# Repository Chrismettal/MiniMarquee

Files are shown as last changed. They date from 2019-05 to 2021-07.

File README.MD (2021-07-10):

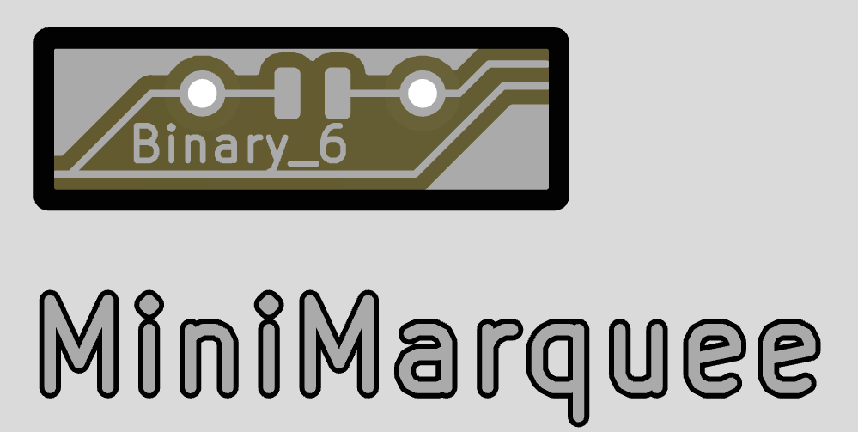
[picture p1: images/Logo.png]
MiniMarqueev0.2Logo


# MOVING TO GITLAB

This project has been moved to Gitlab and will NOT be updated here anymore!

https://gitlab.com/Chrismettal/MiniMarquee

# Update

v0.3 newly uses only a 10uF input cap instead of a 100uF one, since the inrush current when plugging in your PSU made some cheaper 100uF caps fail in rare occasions even with 50% volate derating. a 10uF 35 V cap is effectively using a 2/3 derating and is much less likely to fail, even when cheaper caps are used. Because of the violence of failing tantalum caps a v0.4 will be made that does not use tantalums at all in the future. For that reason v0.3 gerbers are not tested, but have just been generated after changing the silkscreen value of the input cap.

# Buying

I have opened up a Tindie store, carrying PCBs and DIY kits as well as 3D printed parts for this and other projects!



## What is this

Small marquees for standalone decoration with backlit signs, including output for up to 25 W of RGB LED strip.

Might be used for multiple consoles to have the specific sign and indirect strip lighting light up with the console.



## Capabilities

At the moment 15 light scenes can be hardcoded including static light ones and fading between 2 colors. More complex fades can be accomplished at will with any number of calculations with the iFade variables. The amount of light scenes and their values can be modified in the source. The same light scenes will be used for the backlight and the RGB strip output, but the two "zones" can be individually set to display a different scene to enable a contrast between the sign and indirect lighting. A single button steps through the light scenes for the specific zones. The current light scene is always saved in EEPROM to stay persistent between power cycles.

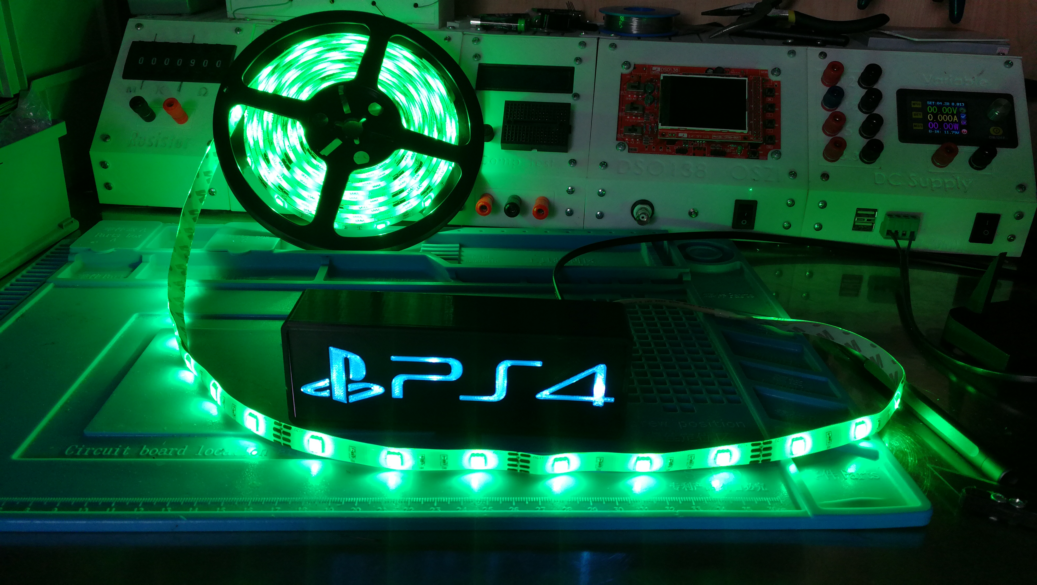
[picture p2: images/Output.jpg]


## DIY

**Be sure to jump straight to the [Wiki](https://github.com/Chrismettal/MiniMarquee/wiki) for detailed build instructions**

All the files are open source. The gerber files as well as the KiCAD project files can be found to get the PCBs made. Alternatively you can just write me. 

The case as well as all the signs need to be 3d printed. For the signs at least a 2-color extruder is required. I print all the parts in PETG because of the selection of transparent materials. The lowermost part i print in white for case internal reflections but if you only have a dual extruder setup you can print the lower and upper parts both in black and the actual logo in your color of choice.

Soldering requires some SMD capabilities. The QFP32 chip is the hardest but with a bit of flux is actually quite doable.

You don't need to change anything in the source if you are fine with the preconfigured lightscenes.
All light scenes are hardcoded in the **LightSceneEvaluation()** function. See the commented examples to make your own scenes. ALso check out the [light scene documentation](https://github.com/Chrismettal/MiniMarquee/wiki/Editing-lightscenes).
I used [PlatformIO](https://platformio.org/) on Visual Studio Code for programming. You could upload the code with the Arduino IDE but i recommend giving PlatformIO a try as you won't have to deal with the libraries etc. yourself.
An ICSP programmer is required to upload code to the board. I used a cheap UsbTiny device but you could use an *Arduino as ISP* for example.

A detailed building guide can be found [here](https://github.com/Chrismettal/MiniMarquee/wiki/Build-guide).

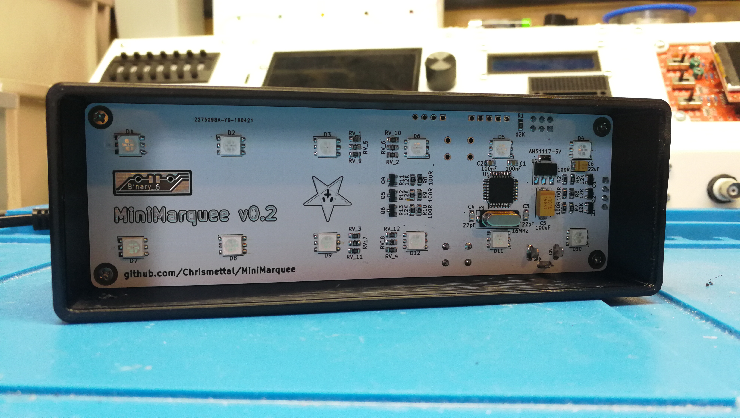
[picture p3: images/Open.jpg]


## Power

The device can be powered directly by a 12 V DC power supply. In my usecase the "master" device that controls the power to the individual consoles also switches on/off the power to the marquees, but you could power the marquees directly from the console using DC-DC converters to make the marquee always switch on with the console. 

## Versions

The current PCB version is v0.2.
The source code is made to be adaptable to both v0.2 and v0.1 PCBs to use with the old revision of the PCB. By default v0.2 is defined in the software. You will have to uncomment the "#define PCB_v0_1" to use the code with the old v0.1 PCB version, should you happen to get your hands on one.

## Controls

- Button short click    --> Next lightscene in current light zone
- Button double click   --> Previous lightscene in current light zone
- Button long click     --> Switch between which light zone to change

The device can just be switched on and off by cutting the power to it. It will remember its lightscenes for the next boot.

## Scenes

For now 15 lightscenes are precoded:

- Red
- Green
- Blue
- Sky Blue
- Warm white
- Cold white
- Yelow
- Orange
- Purple
- Olive
- Slow fade between Red and Green
- Slow fade between Green and Blue
- Slow fade between Blue and Red
- Slow fade between Yellow and Blue
- Breathing white

For not the Scenes are the same for internal and external lightzone but they don't have to be, should you want to change that.

## Signs

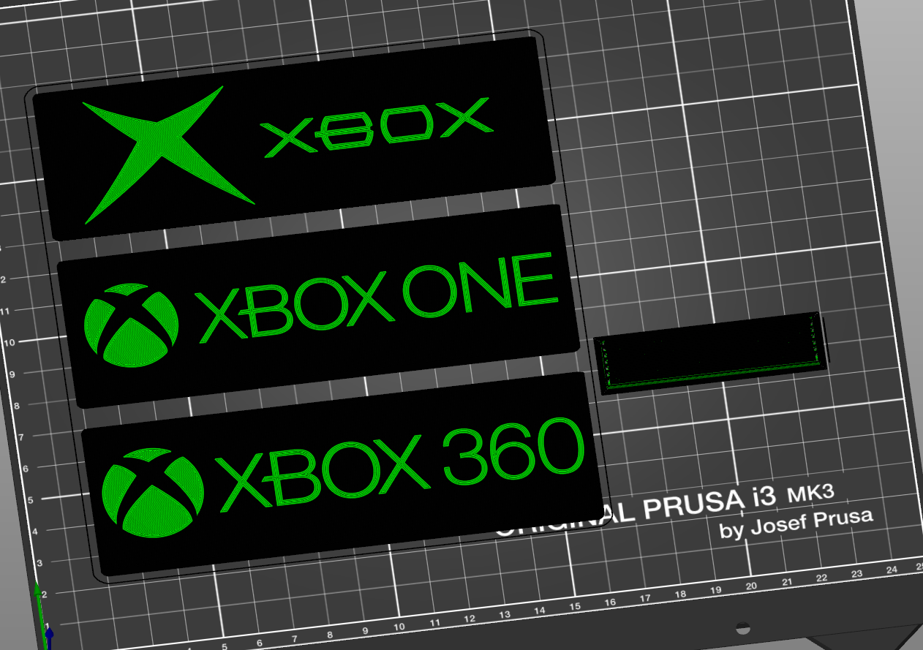
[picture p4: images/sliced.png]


This is an example of some of the designed signs. I am still in the process of printing out every one of them so i don't yet have pictures of all signs ready.

I also uploaded the "RawSign" files in the 3d printable folder so you can design your own signs. Be sure to reupload them either as a remix on [The Thingiverse page](https://www.thingiverse.com/thing:3683055) or somewhere else where i can feed them back into here.

Here is a list of the already made signs:

- [ ]  Nintendo
- [x]  NES
- [x]  SNES
- [x]  N64
- [x]  GC
- [x]  Wii
- [x]  WiiU
- [x]  Switch
- [x]  PS1
- [x]  PS2
- [x]  PS3
- [x]  PS4
- [x]  Xbox Classic
- [x]  Xbox 360
- [x]  Xbox One
- [ ]  Sega
- [x]  Master System
- [x]  Genesis
- [ ]  Megadrive
- [x]  Dreamcast
- [x]  Atari 2600
- [x]  NeoGeo
- [x]  Commodore
- [ ]  PC Engine
- [ ]  Turbografx 16
- [x]  Diffuse plate for stickers

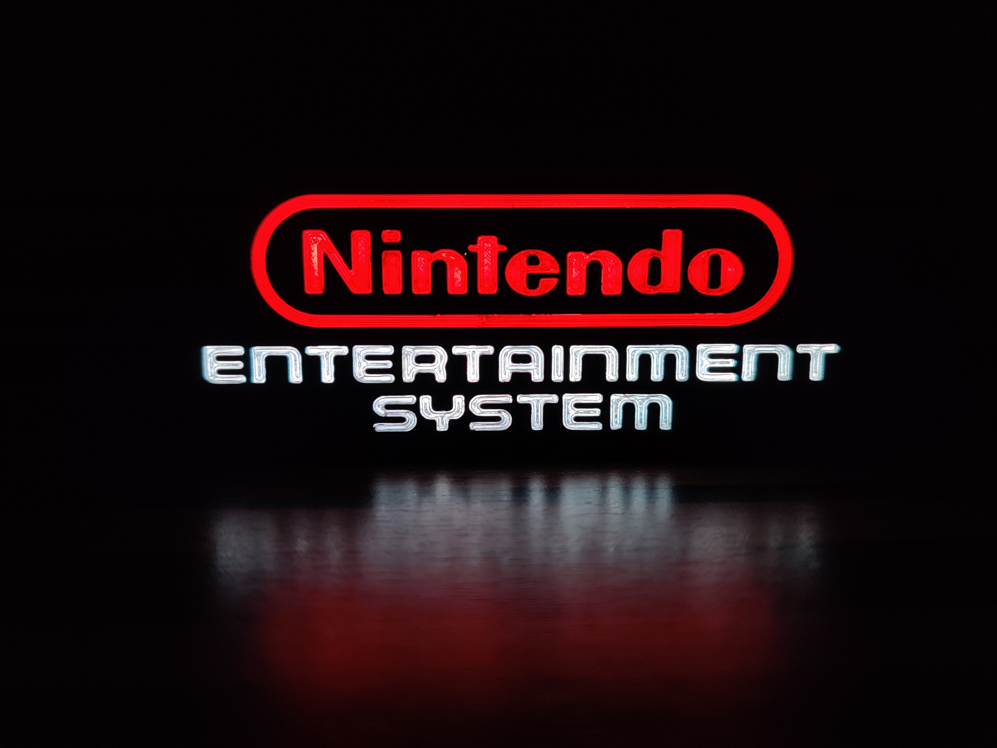
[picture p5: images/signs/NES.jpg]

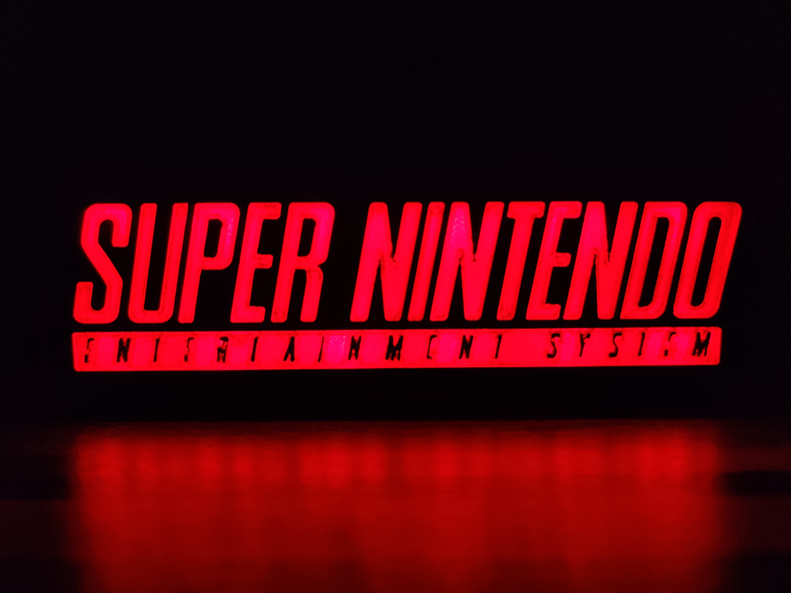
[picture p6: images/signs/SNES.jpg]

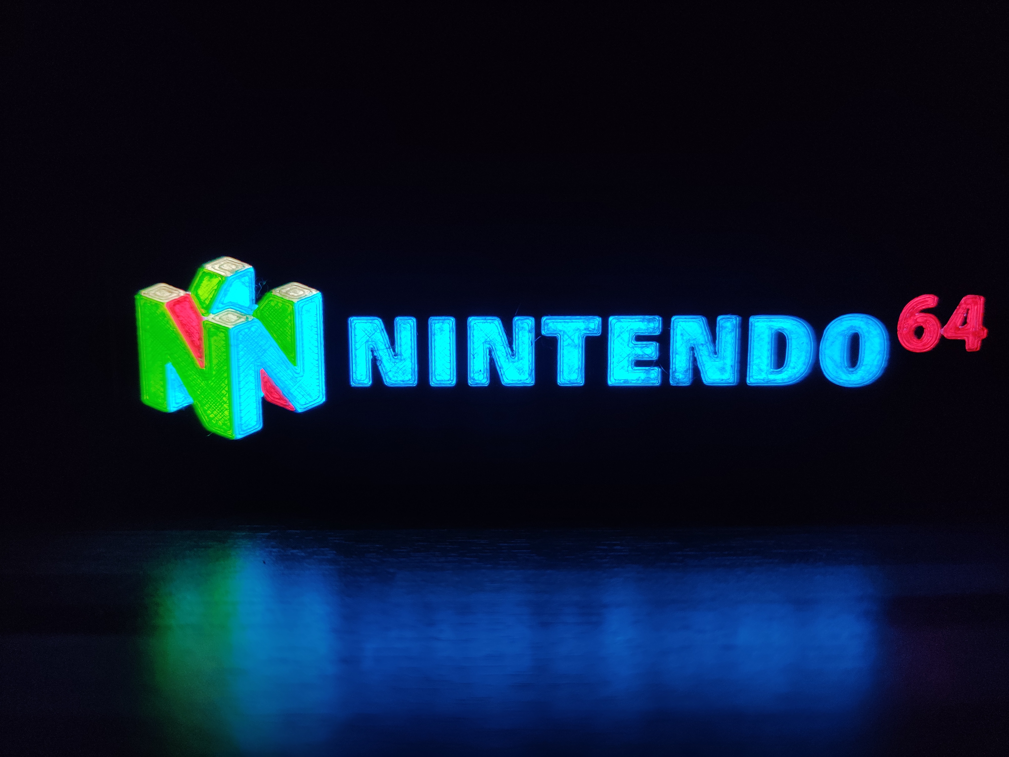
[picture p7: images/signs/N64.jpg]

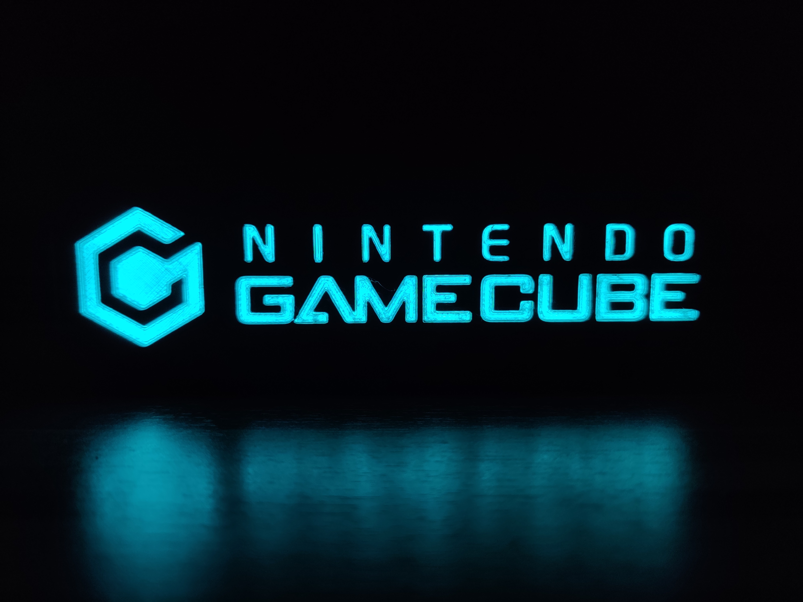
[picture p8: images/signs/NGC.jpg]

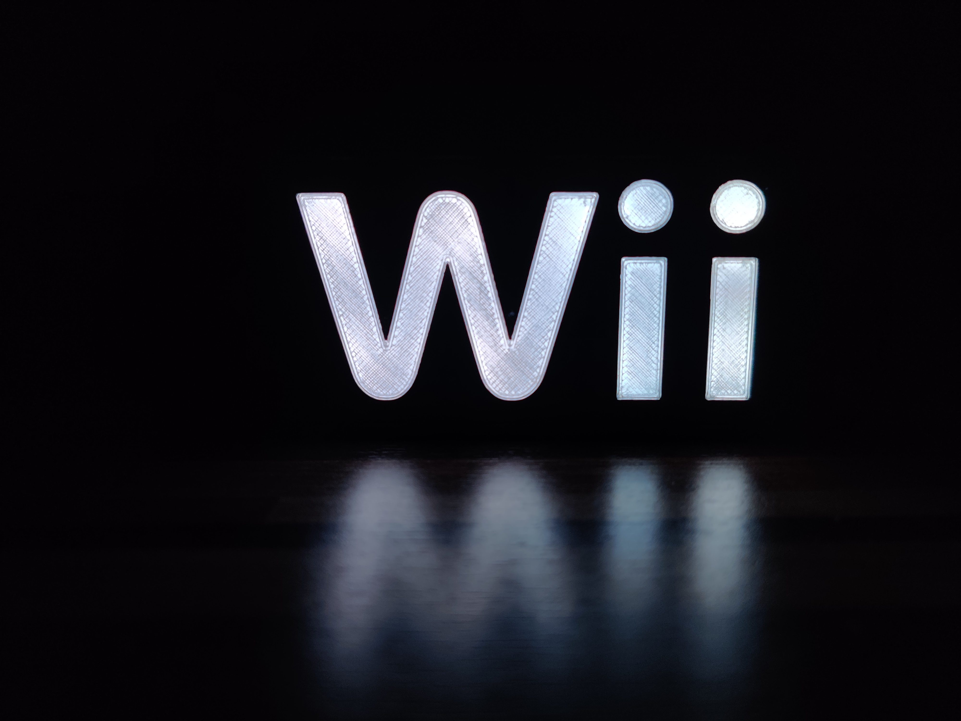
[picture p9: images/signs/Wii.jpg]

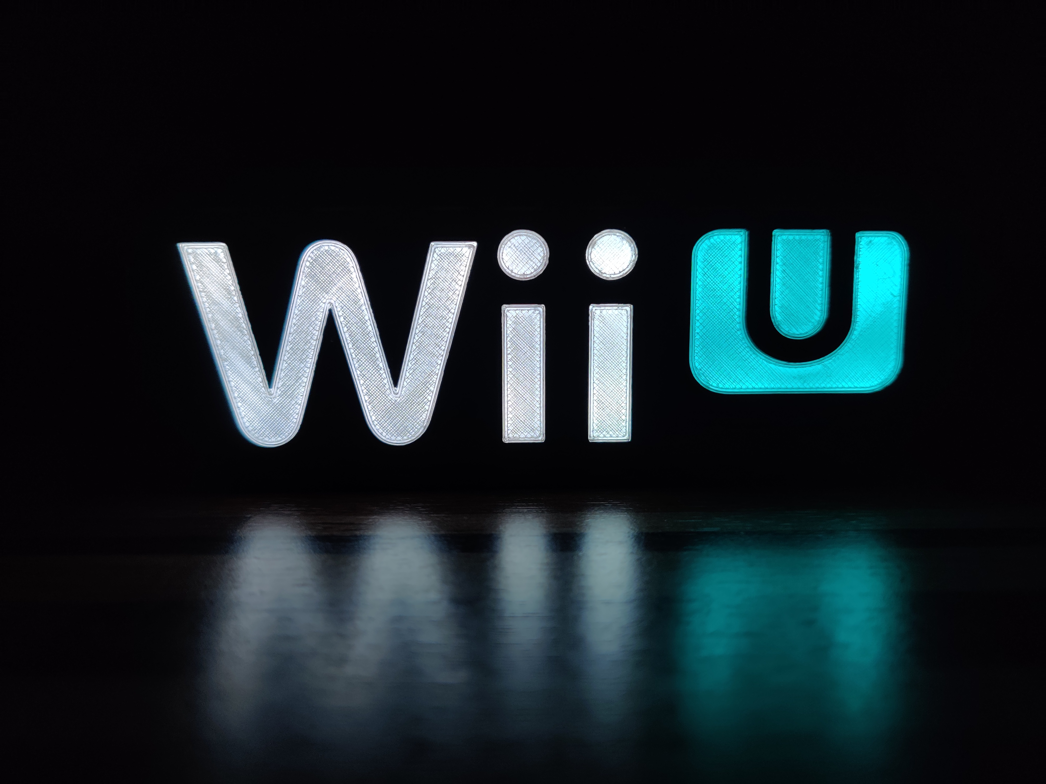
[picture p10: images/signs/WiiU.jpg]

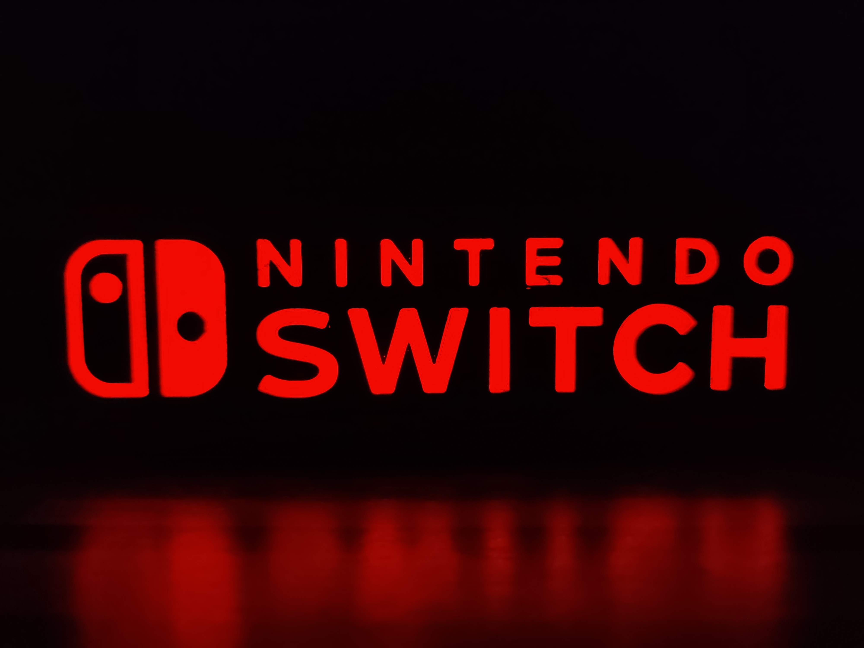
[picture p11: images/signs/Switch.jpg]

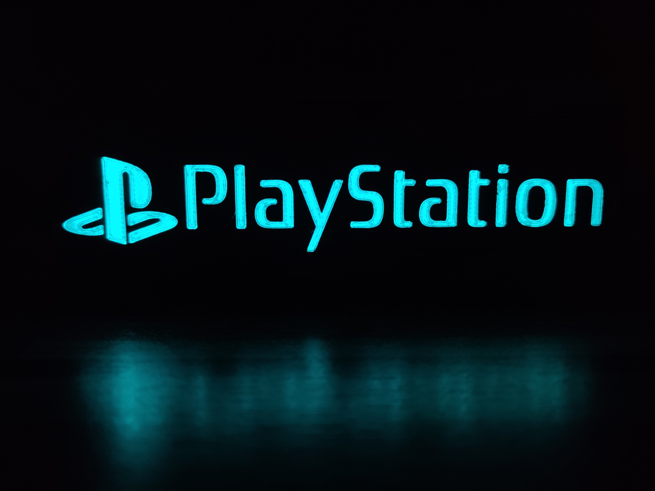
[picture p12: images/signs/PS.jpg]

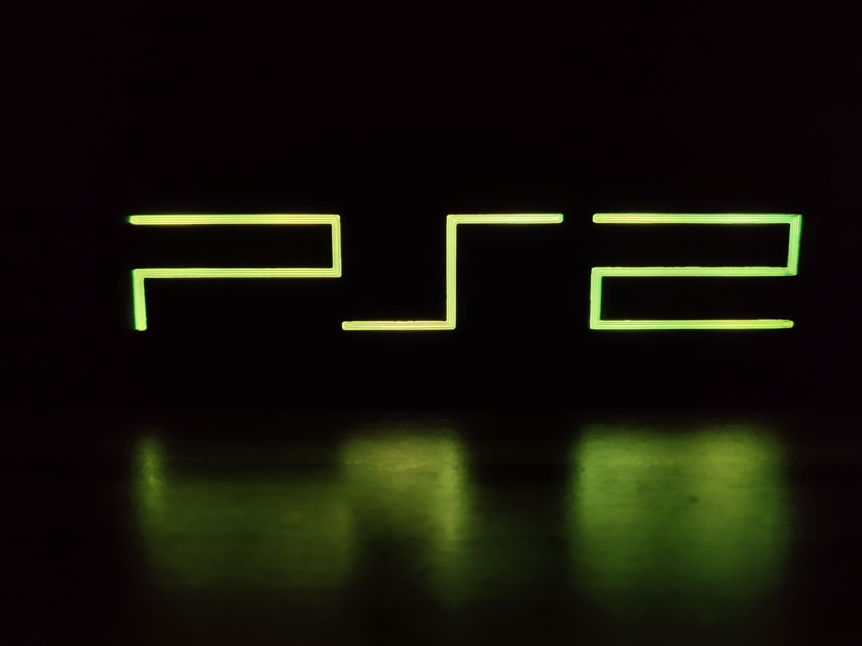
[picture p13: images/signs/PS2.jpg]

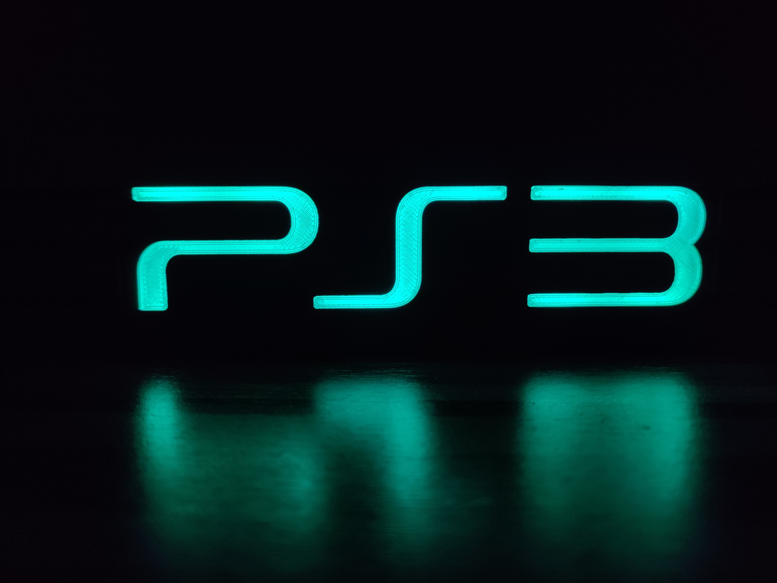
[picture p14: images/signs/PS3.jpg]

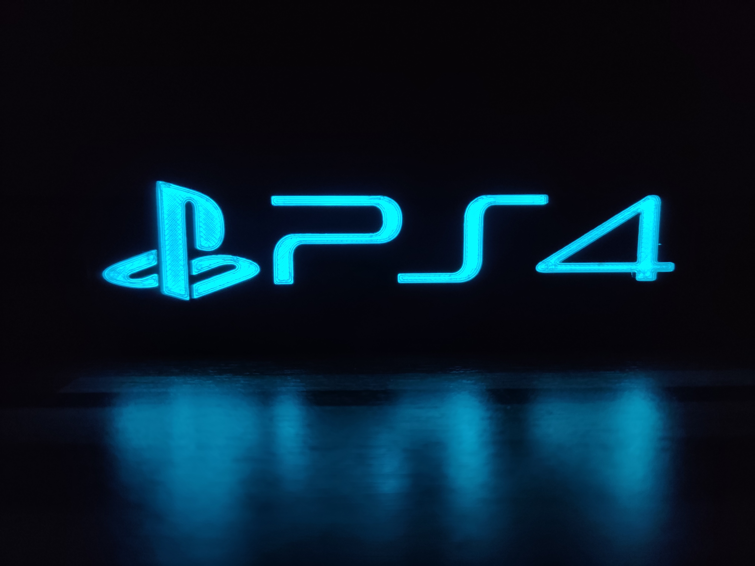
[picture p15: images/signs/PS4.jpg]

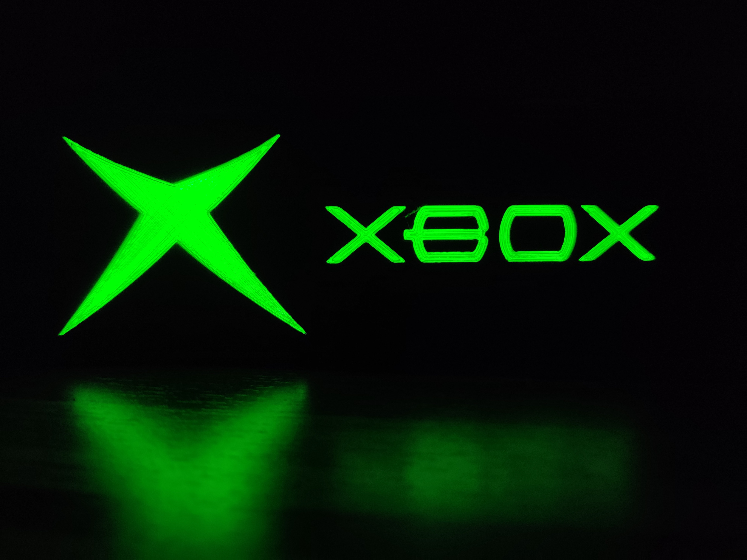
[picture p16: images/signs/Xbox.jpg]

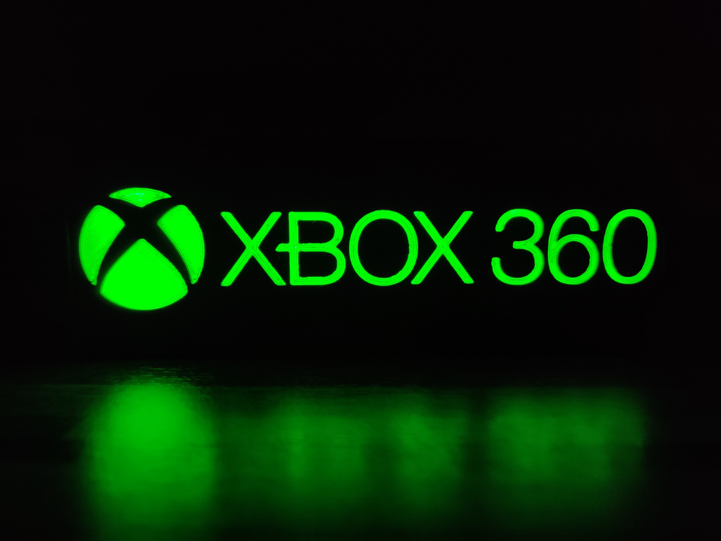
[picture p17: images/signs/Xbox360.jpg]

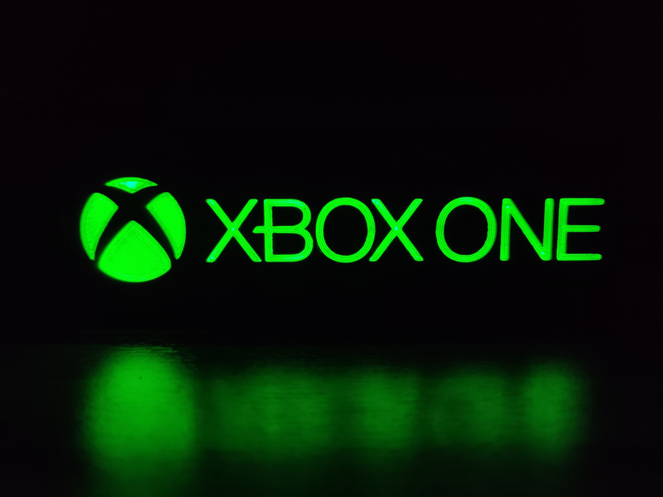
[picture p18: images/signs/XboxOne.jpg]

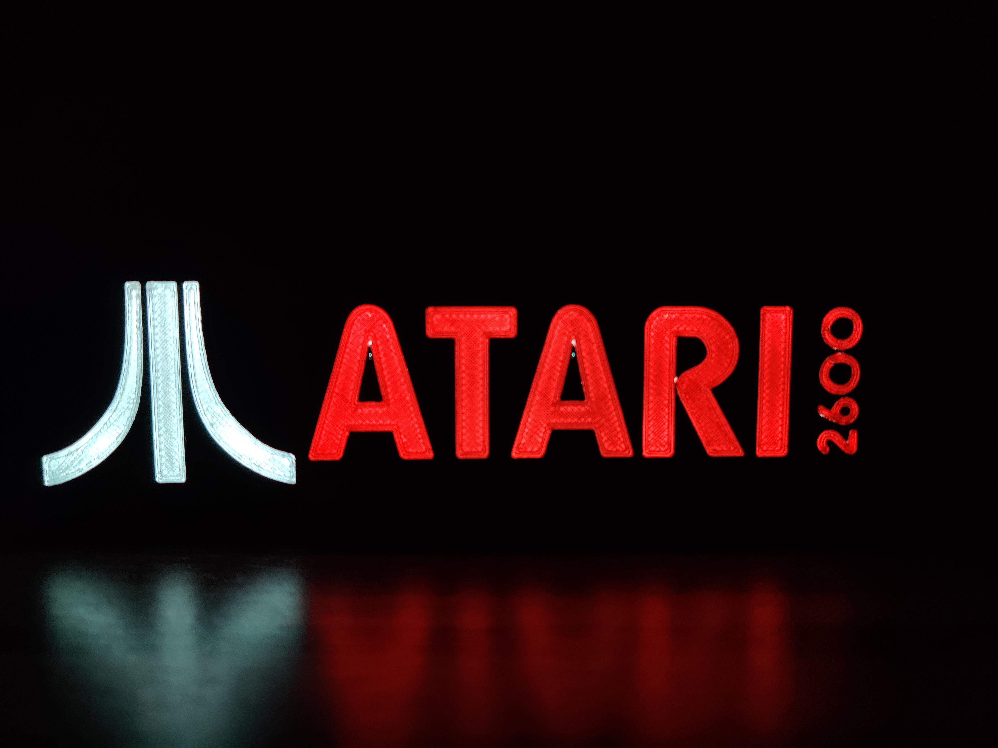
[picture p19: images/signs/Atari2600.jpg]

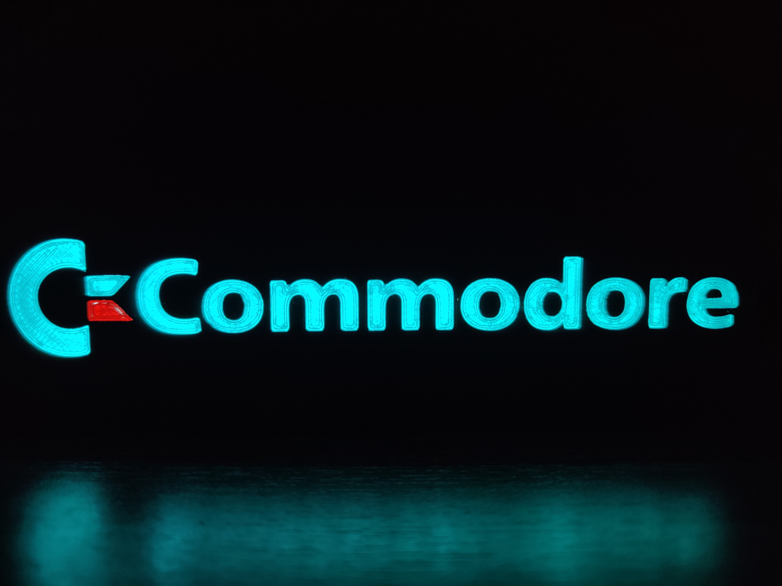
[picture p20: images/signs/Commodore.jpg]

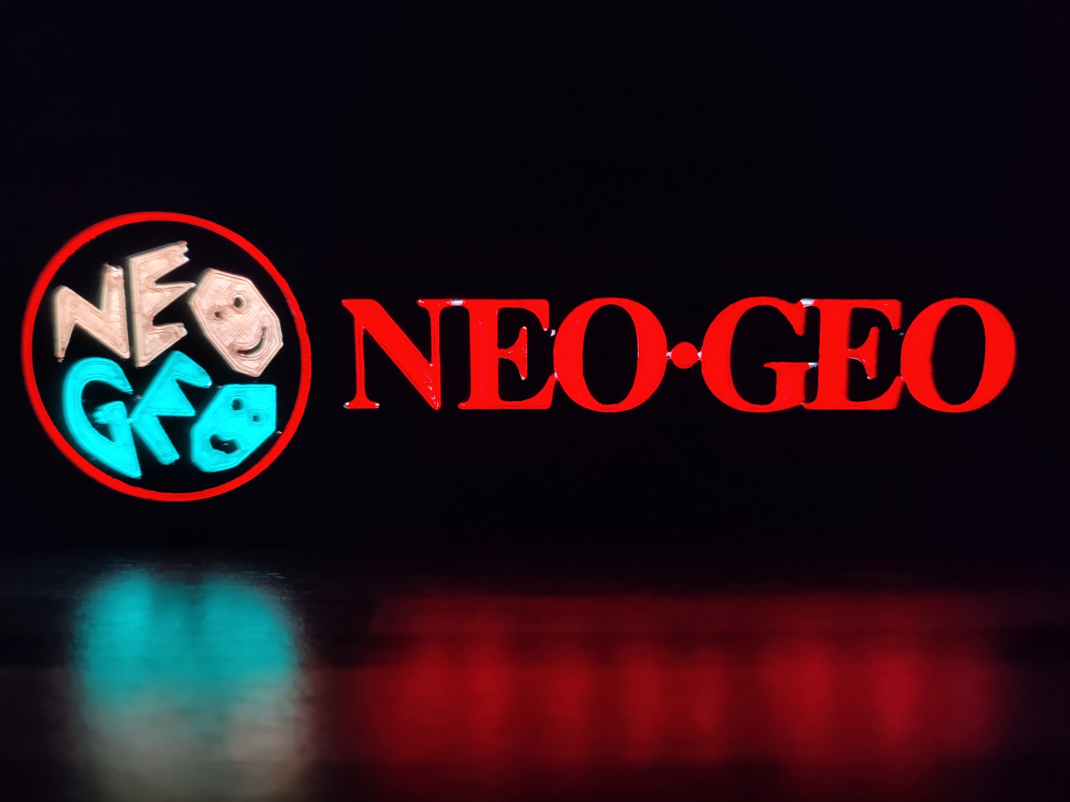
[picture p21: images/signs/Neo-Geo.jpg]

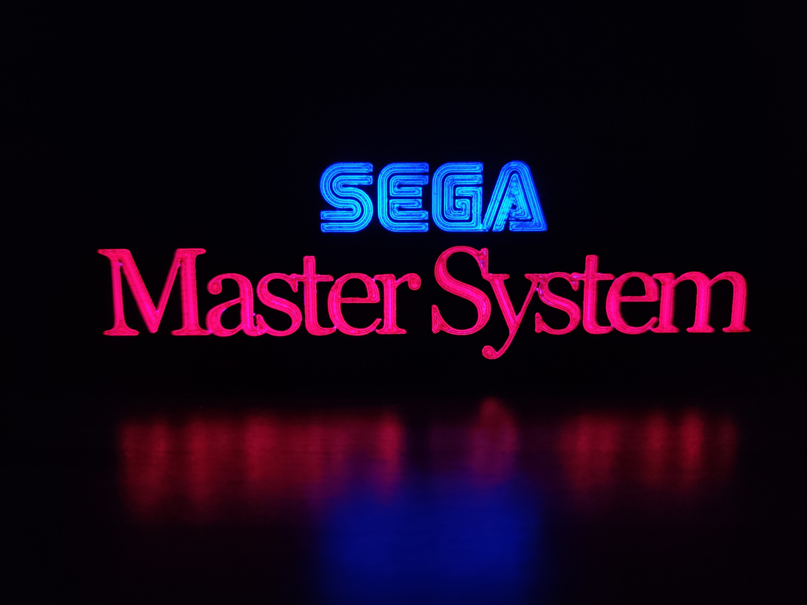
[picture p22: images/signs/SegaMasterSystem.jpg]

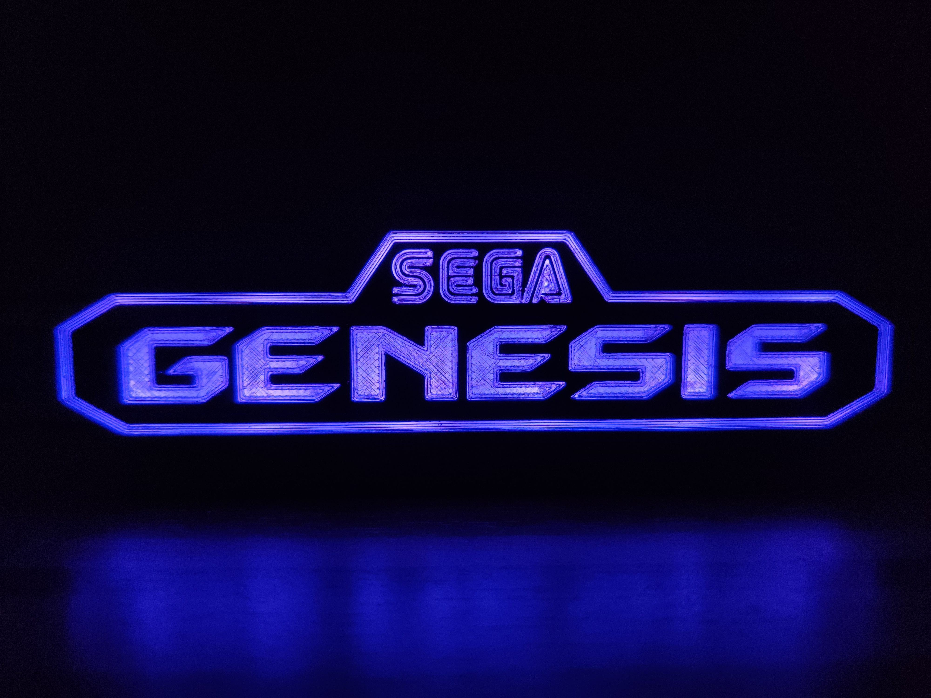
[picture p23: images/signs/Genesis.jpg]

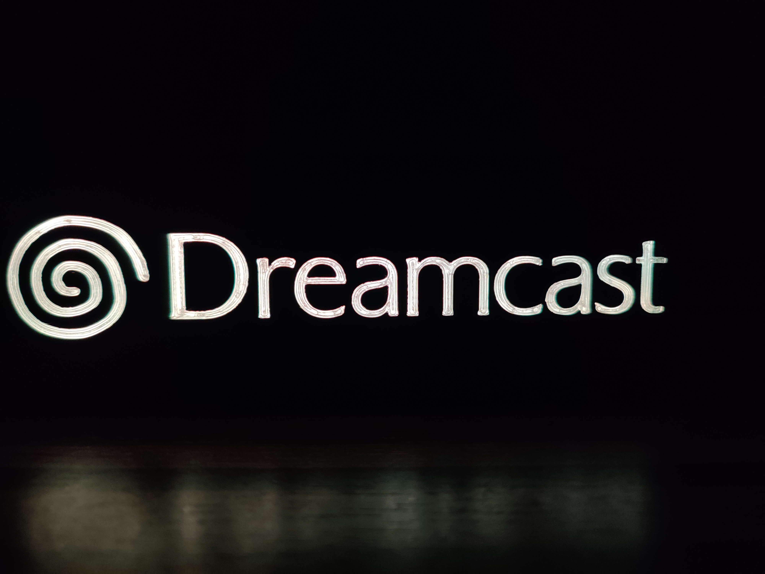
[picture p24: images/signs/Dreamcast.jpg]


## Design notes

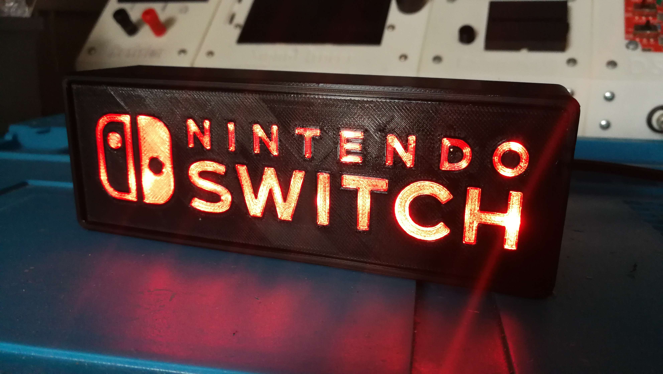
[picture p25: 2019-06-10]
images/Finished.jpg

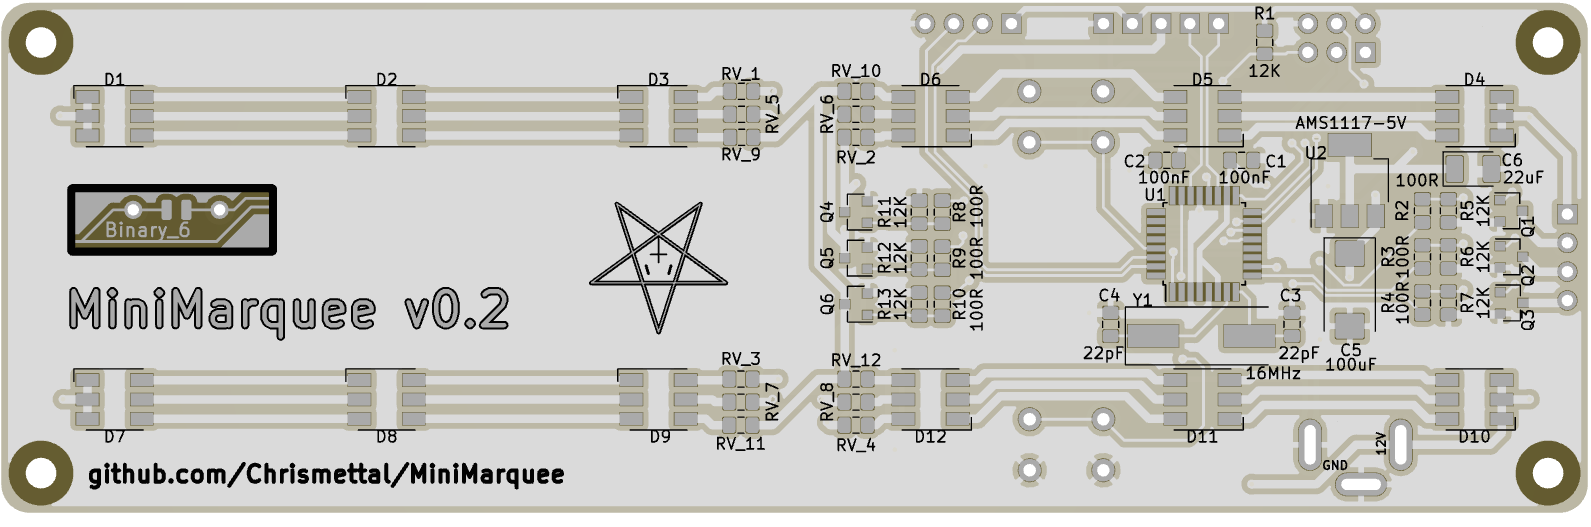
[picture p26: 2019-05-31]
images/PCB Front.png

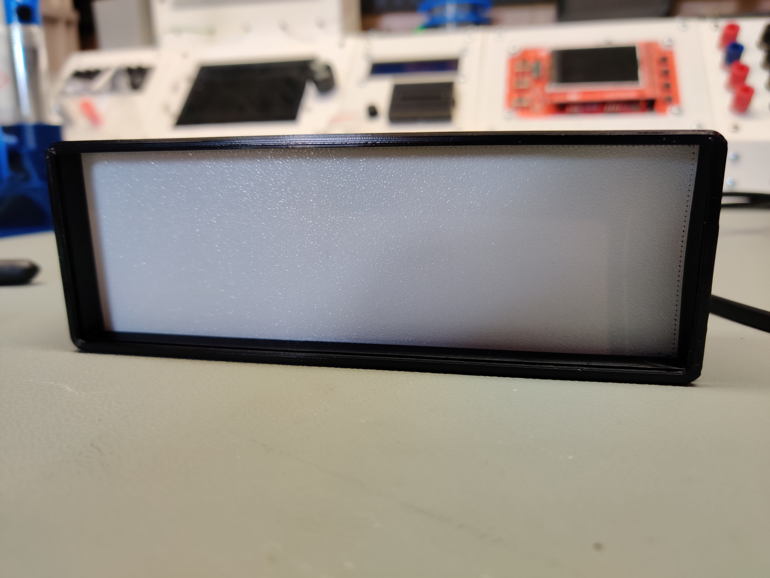
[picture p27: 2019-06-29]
images/diffusor.jpg

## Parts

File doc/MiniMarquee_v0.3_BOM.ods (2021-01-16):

Qty | Reference(s) | Value | Footprint | Comment
 | Fixed parts
7 | R1, R5, R6, R7, R11, R12, R13 | 12K | SMD 0805
6 | R2, R3, R4, R8, R9, R10 | 100R | SMD 0805
2 | C1, C2 | 100nF | Ceramic SMD 0805
2 | C3, C4 | 22pF | Ceramic SMD 0805
1 | C5 | 10uF 35 V | Tantalum D7343 | Double check polarity if you
1 | C6 | 22uF | Tantalum B3528 | do not want to „boom“ your cap
12 | D1, D2, D3, D4, D5, D6, D7, D8, D9, D10, D11, D12 | LED_RGB | LED_RGB_5050-6 / PLCC-6 | Check your pinout! See below
6 | Q1, Q2, Q3, Q4, Q5, Q6 | FDN337N | SOT-23
1 | U1 | ATMEGA168-20AU | TQFP-32_7x7mm_P0.8mm
1 | U2 | AMS1117-5V | SOT-223-3_TabPin2
1 | Y1 | 16MHz | Crystal_SMD_HC49-SD
1 | SW_LED1 | SW_Push | Pushbutton_6mm_H13mm
1 | SW_RST1 | SW_Push | Pusbutton_6mm | Optional reset button
1 | J6 | Barrel_Jack | Panel mount standing barrel jack 5.5x2.1mm | The cheap chinese ones
 | Variable parts
4 | RV_1, RV_2, RV_3, RV_4 | 150R | SMD 0805 | Resistor LED pin 1-2 (B for me)
4 | RV_5, RV_6, RV_7, RV_8 | 220R | SMD 0805 | Resistor LED pin 2-5 (R for me)
4 | RV_9, RV_10, RV_11, RV_12 | 150R | SMD 0805 | Resistor LED pin 3-4 (G for me)
 | Double check your RGB LED pinout and required resistors for the colors.
 | My pinout is not neccessarily the same as yours and my resistors may
 | differ from what your LEDs need. My values result in rather high
 | LED currents of around 30mA.
 | If your pinout is different you should change the pinout in the source code
 | otherwise the light scenes will be „distorted“

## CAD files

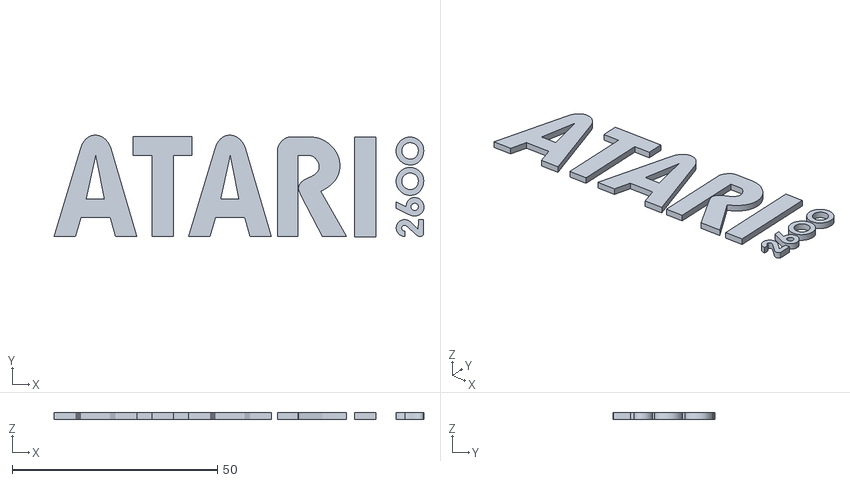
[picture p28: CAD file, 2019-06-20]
3D/Printable_v0.2/Atari/2600/2600_red.stl
90.2 x 24.8 x 1.60

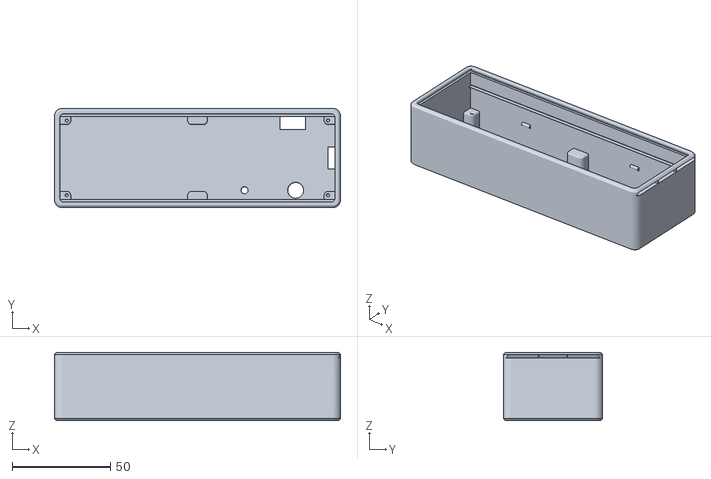
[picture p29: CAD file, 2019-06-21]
3D/Printable_v0.2/Case_singlecolor_r4.stl
145.6 x 50.6 x 34.8

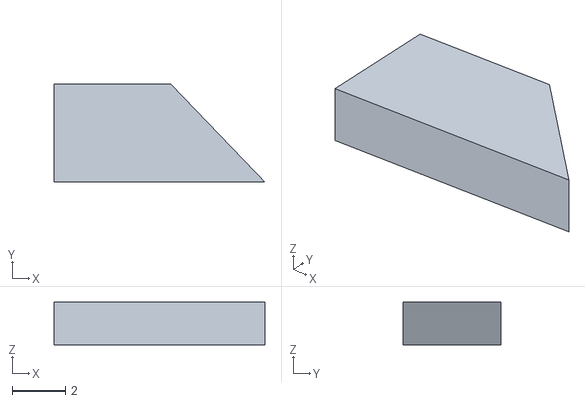
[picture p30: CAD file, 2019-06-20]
3D/Printable_v0.2/Commodore/Com_red.stl
7.94 x 3.70 x 1.60

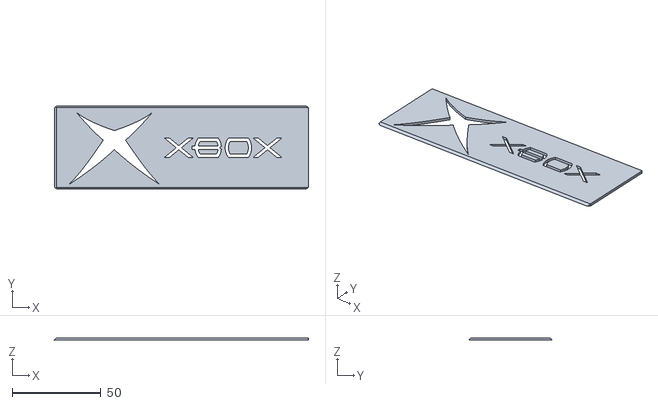
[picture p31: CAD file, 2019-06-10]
3D/Printable_v0.2/Microsoft/Xbox/Xbox_blk.stl
142.9 x 46.9 x 1.40

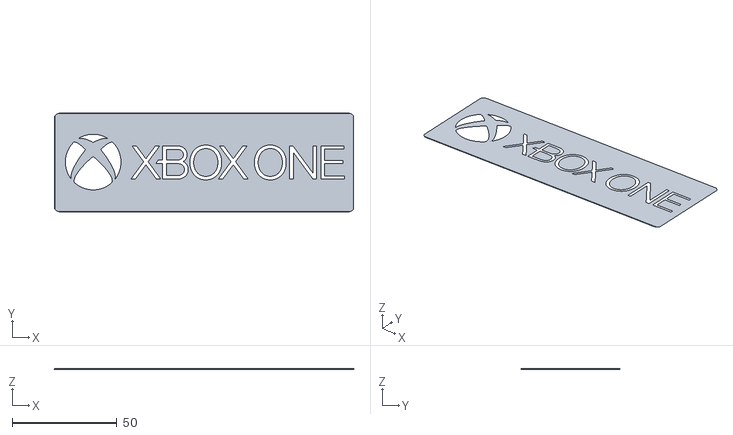
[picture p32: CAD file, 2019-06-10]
3D/Printable_v0.2/Microsoft/XboxOne/XboxOne_wh.stl
143.0 x 47.2 x 0.2

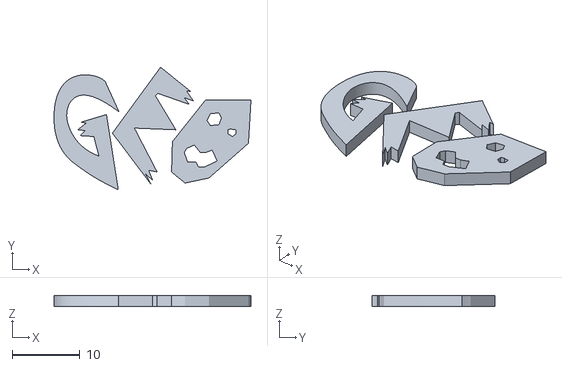
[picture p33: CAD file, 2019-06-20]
3D/Printable_v0.2/NeoGeo/NeoGeo_blu.stl
29.1 x 18.1 x 1.60

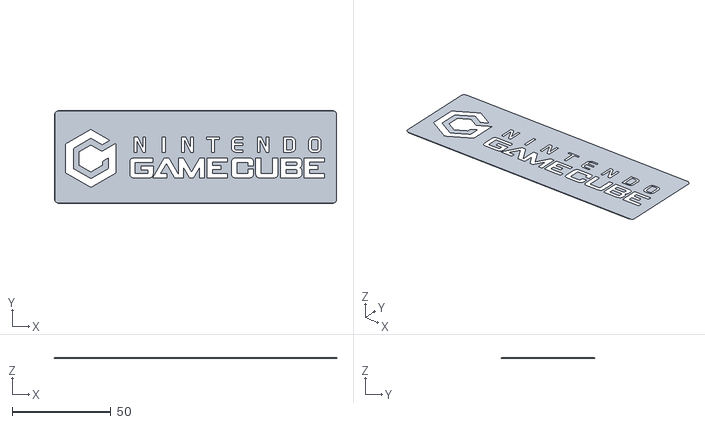
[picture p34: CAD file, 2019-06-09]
3D/Printable_v0.2/Nintendo/GC/GC_wh.stl
143.0 x 47.2 x 0.2

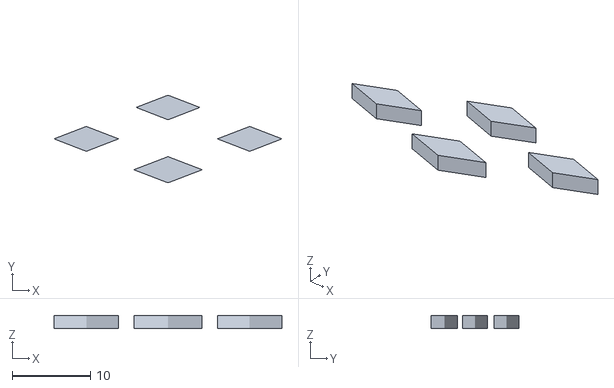
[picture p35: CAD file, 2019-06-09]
3D/Printable_v0.2/Nintendo/N64/N64_yel.stl
29.1 x 11.2 x 1.60

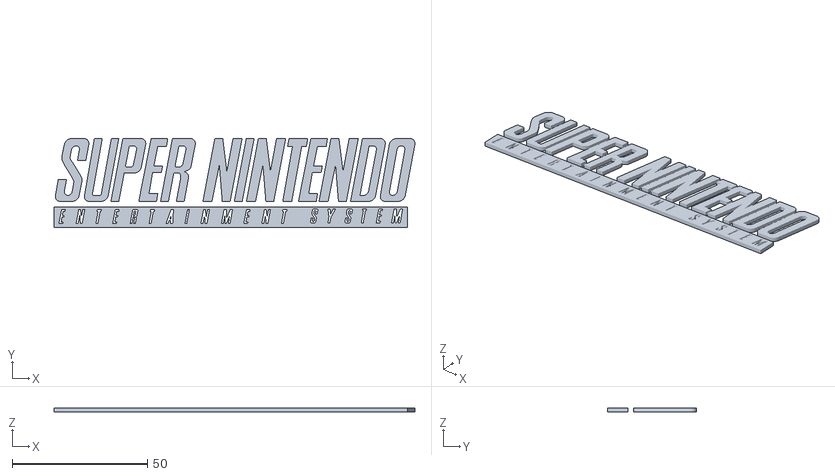
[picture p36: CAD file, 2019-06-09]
3D/Printable_v0.2/Nintendo/SNES/SNES_red.stl
133.4 x 32.9 x 1.60

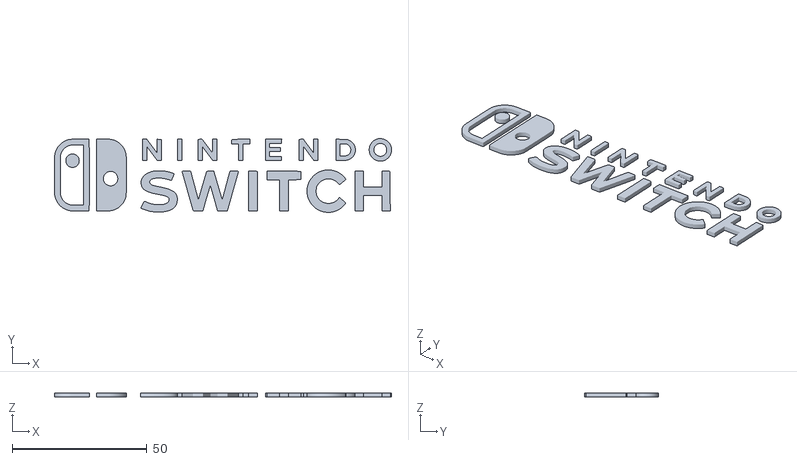
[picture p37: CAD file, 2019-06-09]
3D/Printable_v0.2/Nintendo/Switch/Switch_red.stl
125.0 x 27.4 x 1.60

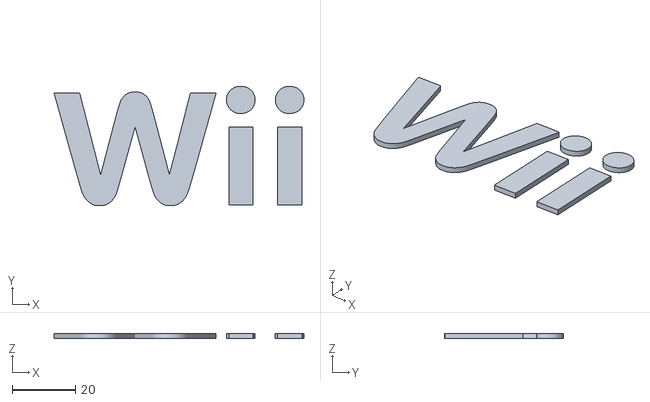
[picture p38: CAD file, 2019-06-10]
3D/Printable_v0.2/Nintendo/Wii/Wii_blu.stl
78.9 x 37.7 x 1.60

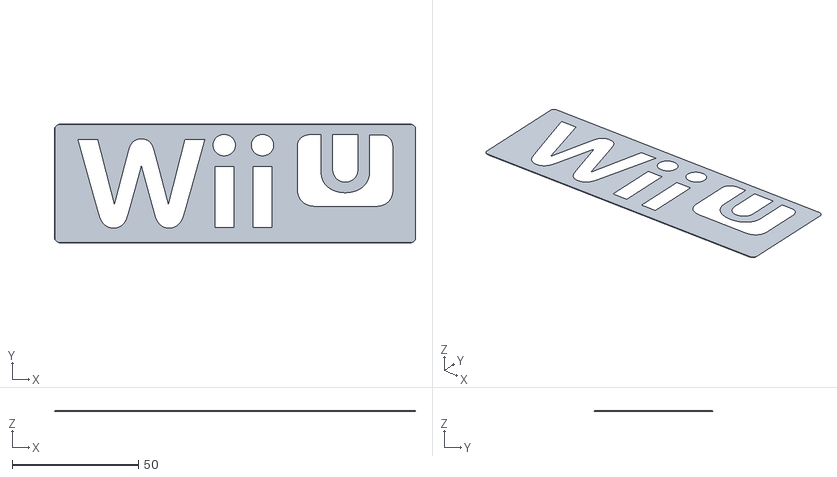
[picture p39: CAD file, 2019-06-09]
3D/Printable_v0.2/Nintendo/WiiU/WiiU_wh.stl
143.0 x 47.2 x 0.2

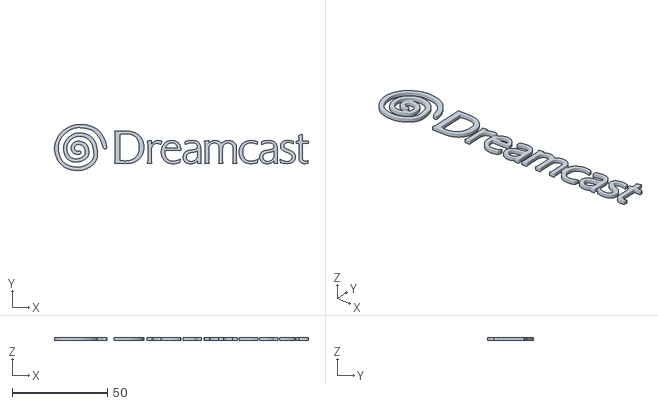
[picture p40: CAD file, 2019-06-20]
3D/Printable_v0.2/Sega/Dreamcast/Sega_DC_clr.stl
133.1 x 24.3 x 1.60

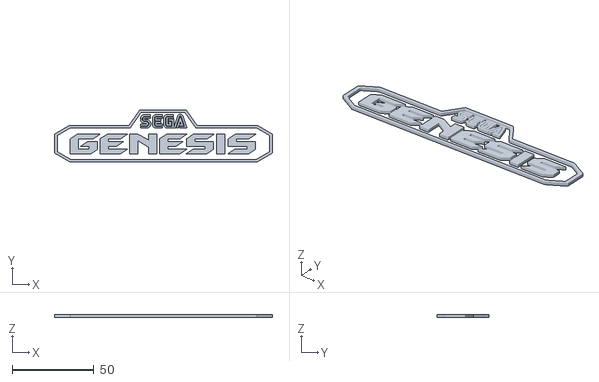
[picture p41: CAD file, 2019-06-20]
3D/Printable_v0.2/Sega/Genesis/Genesis_clr.stl
133.5 x 31.9 x 1.60

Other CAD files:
3D/Printable_v0.2/Microsoft/Xbox360/Xbox360_blk.stl
3D/Printable_v0.2/Nintendo/NES/NES_blk.stl
3D/Printable_v0.2/Sega/MasterSystem/Sega_MS_blk.stl
3D/Printable_v0.2/Sony/PS1/PS1_wh.stl
3D/Printable_v0.2/Atari/2600/2600_blk.stl
3D/Printable_v0.2/Atari/2600/2600_clr.stl
3D/Printable_v0.2/Atari/2600/2600_wh.stl
3D/Printable_v0.2/Commodore/Com_blk.stl
3D/Printable_v0.2/Commodore/Com_blu.stl
3D/Printable_v0.2/Commodore/Com_wh.stl
3D/Printable_v0.2/Diffusor_wh.stl
3D/Printable_v0.2/Microsoft/Xbox/Xbox_grn.stl
3D/Printable_v0.2/Microsoft/Xbox/Xbox_wh.stl
3D/Printable_v0.2/Microsoft/Xbox360/Xbox360_grn.stl
3D/Printable_v0.2/Microsoft/Xbox360/Xbox360_wh.stl
3D/Printable_v0.2/Microsoft/XboxOne/XboxOne_blk.stl
3D/Printable_v0.2/Microsoft/XboxOne/XboxOne_grn.stl
3D/Printable_v0.2/NeoGeo/NeoGeo_blk.stl
3D/Printable_v0.2/NeoGeo/NeoGeo_red.stl
3D/Printable_v0.2/NeoGeo/NeoGeo_wh.stl
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

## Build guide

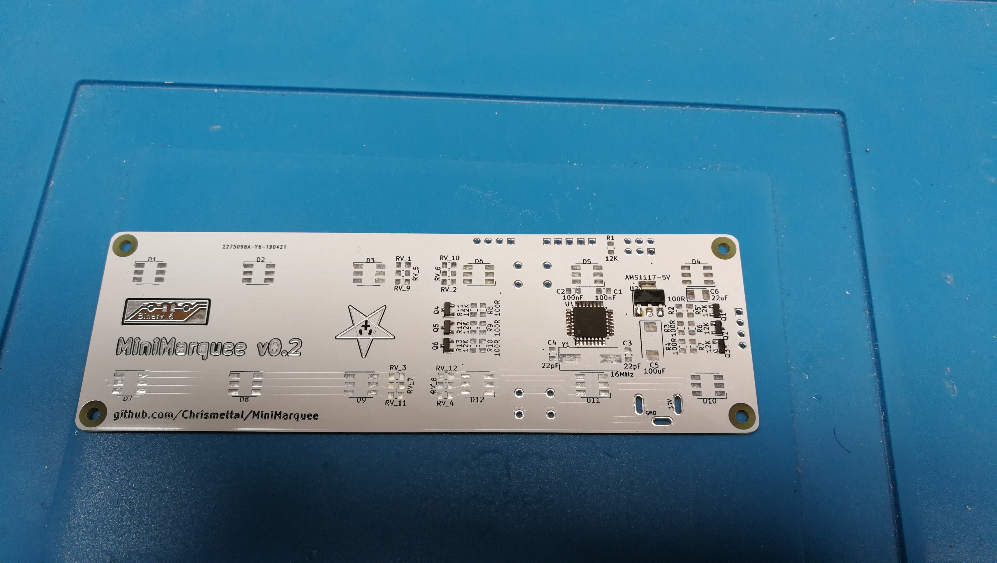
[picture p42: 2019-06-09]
images/Manual2.jpg

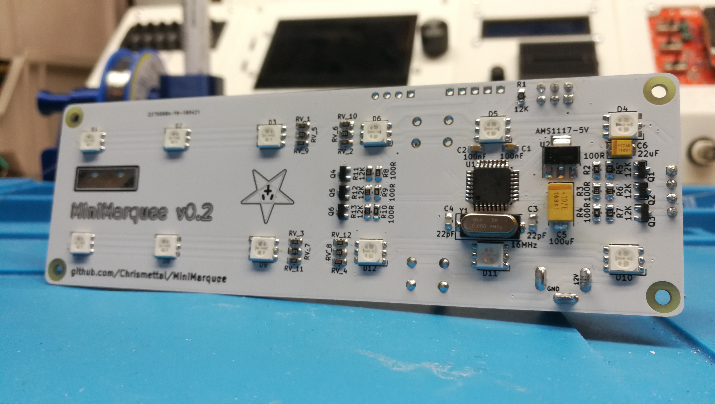
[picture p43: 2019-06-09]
images/Manual9.jpg

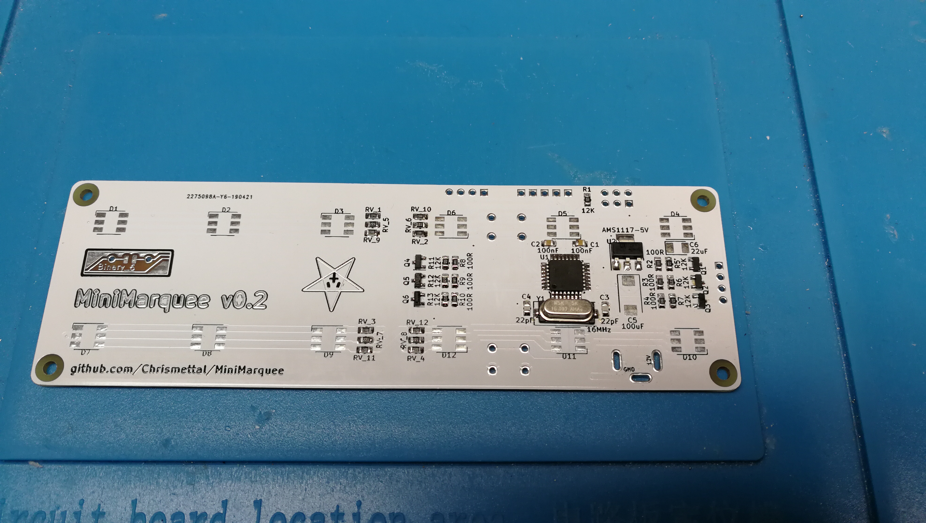
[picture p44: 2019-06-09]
images/Manual4.jpg

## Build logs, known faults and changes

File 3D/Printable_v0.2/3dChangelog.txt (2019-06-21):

Case_Singlecolor
	r3:
	-Added screwless clamps for PCB
	-Added slots for diffusor screen
	
	r4:
	-Better mount for diffusor screen

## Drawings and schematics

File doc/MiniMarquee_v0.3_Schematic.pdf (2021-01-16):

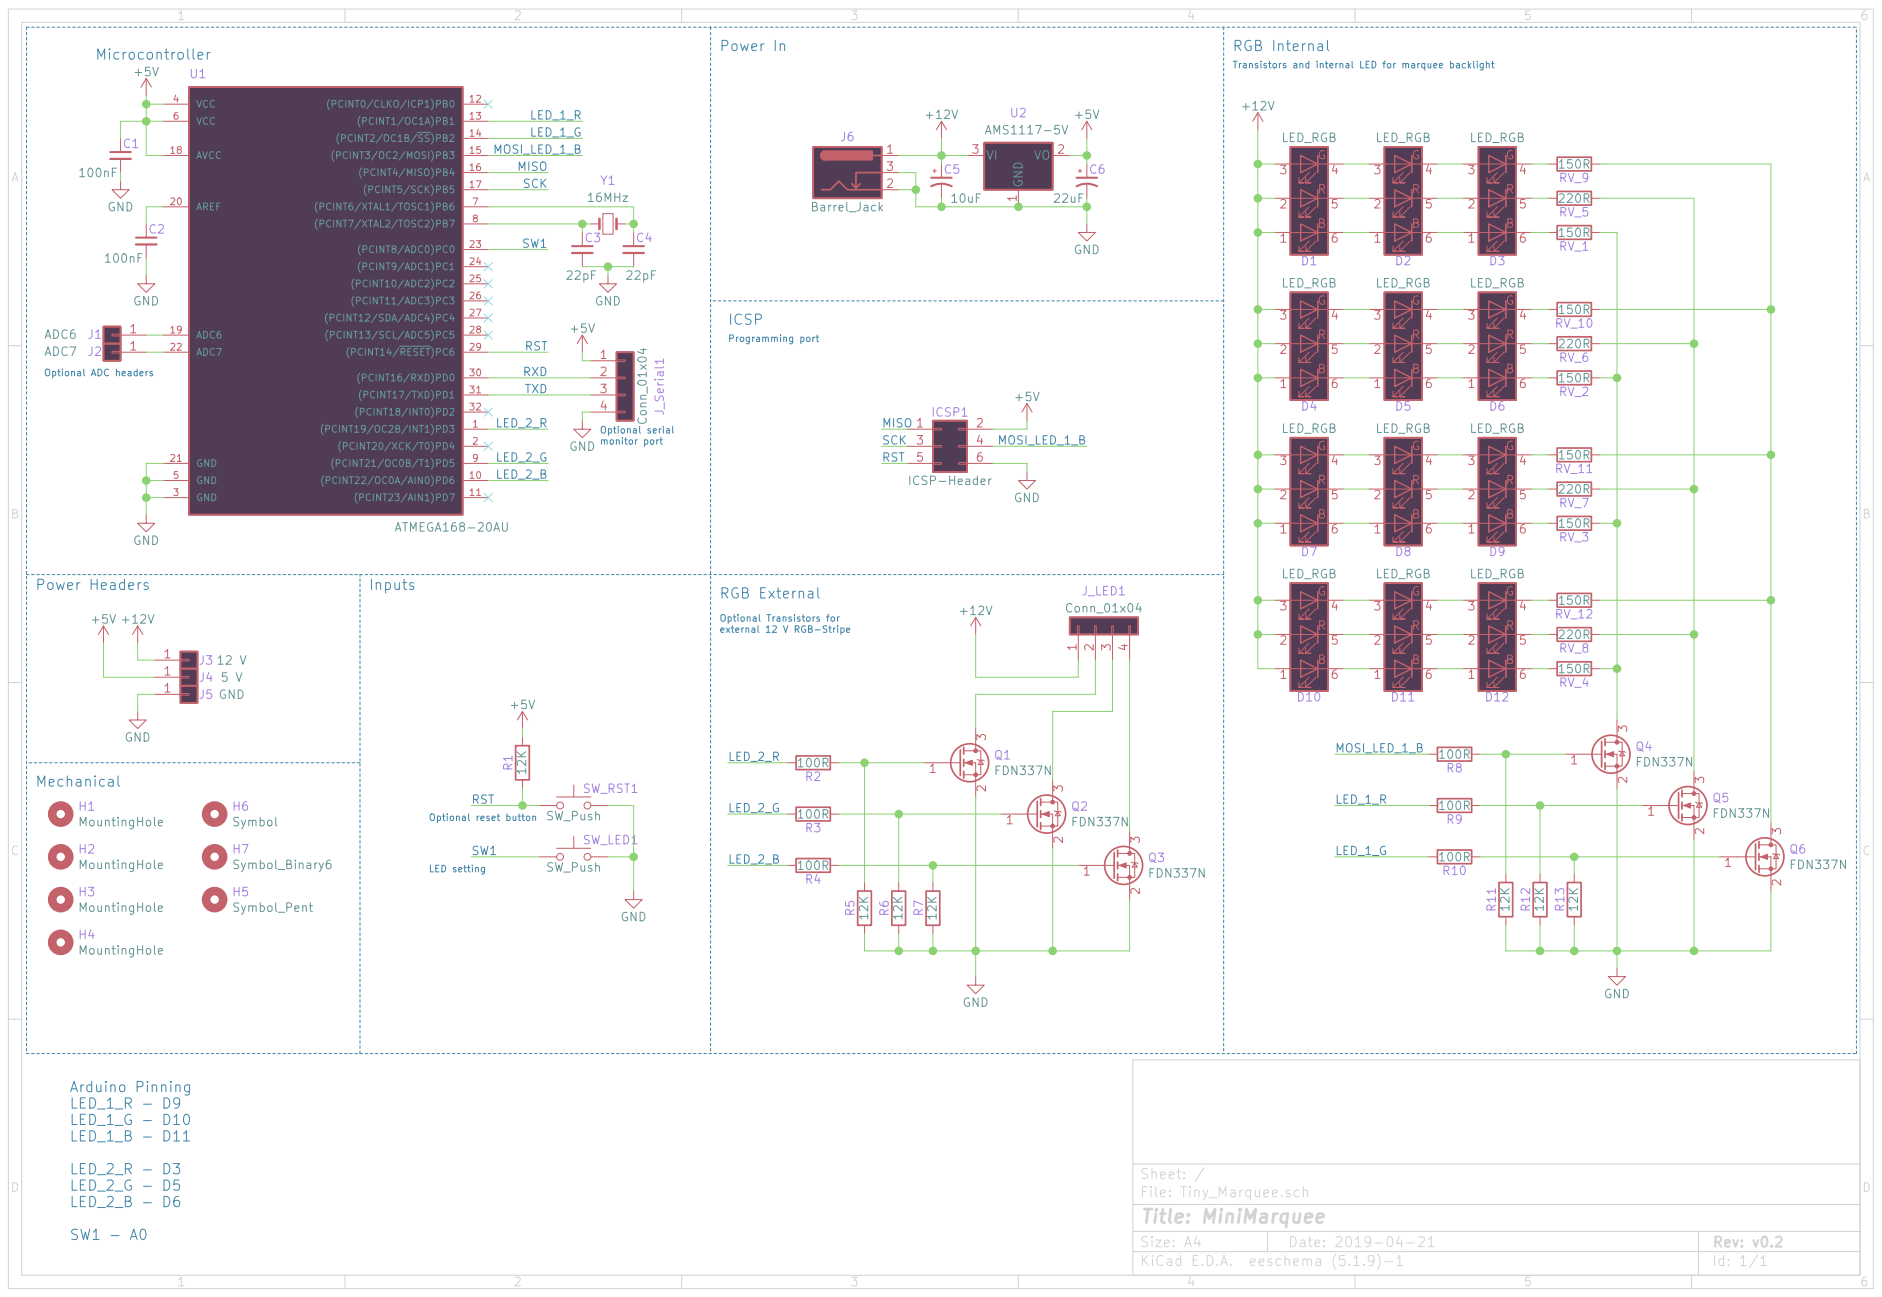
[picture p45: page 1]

RGB Internal

LED setting Optional reset button

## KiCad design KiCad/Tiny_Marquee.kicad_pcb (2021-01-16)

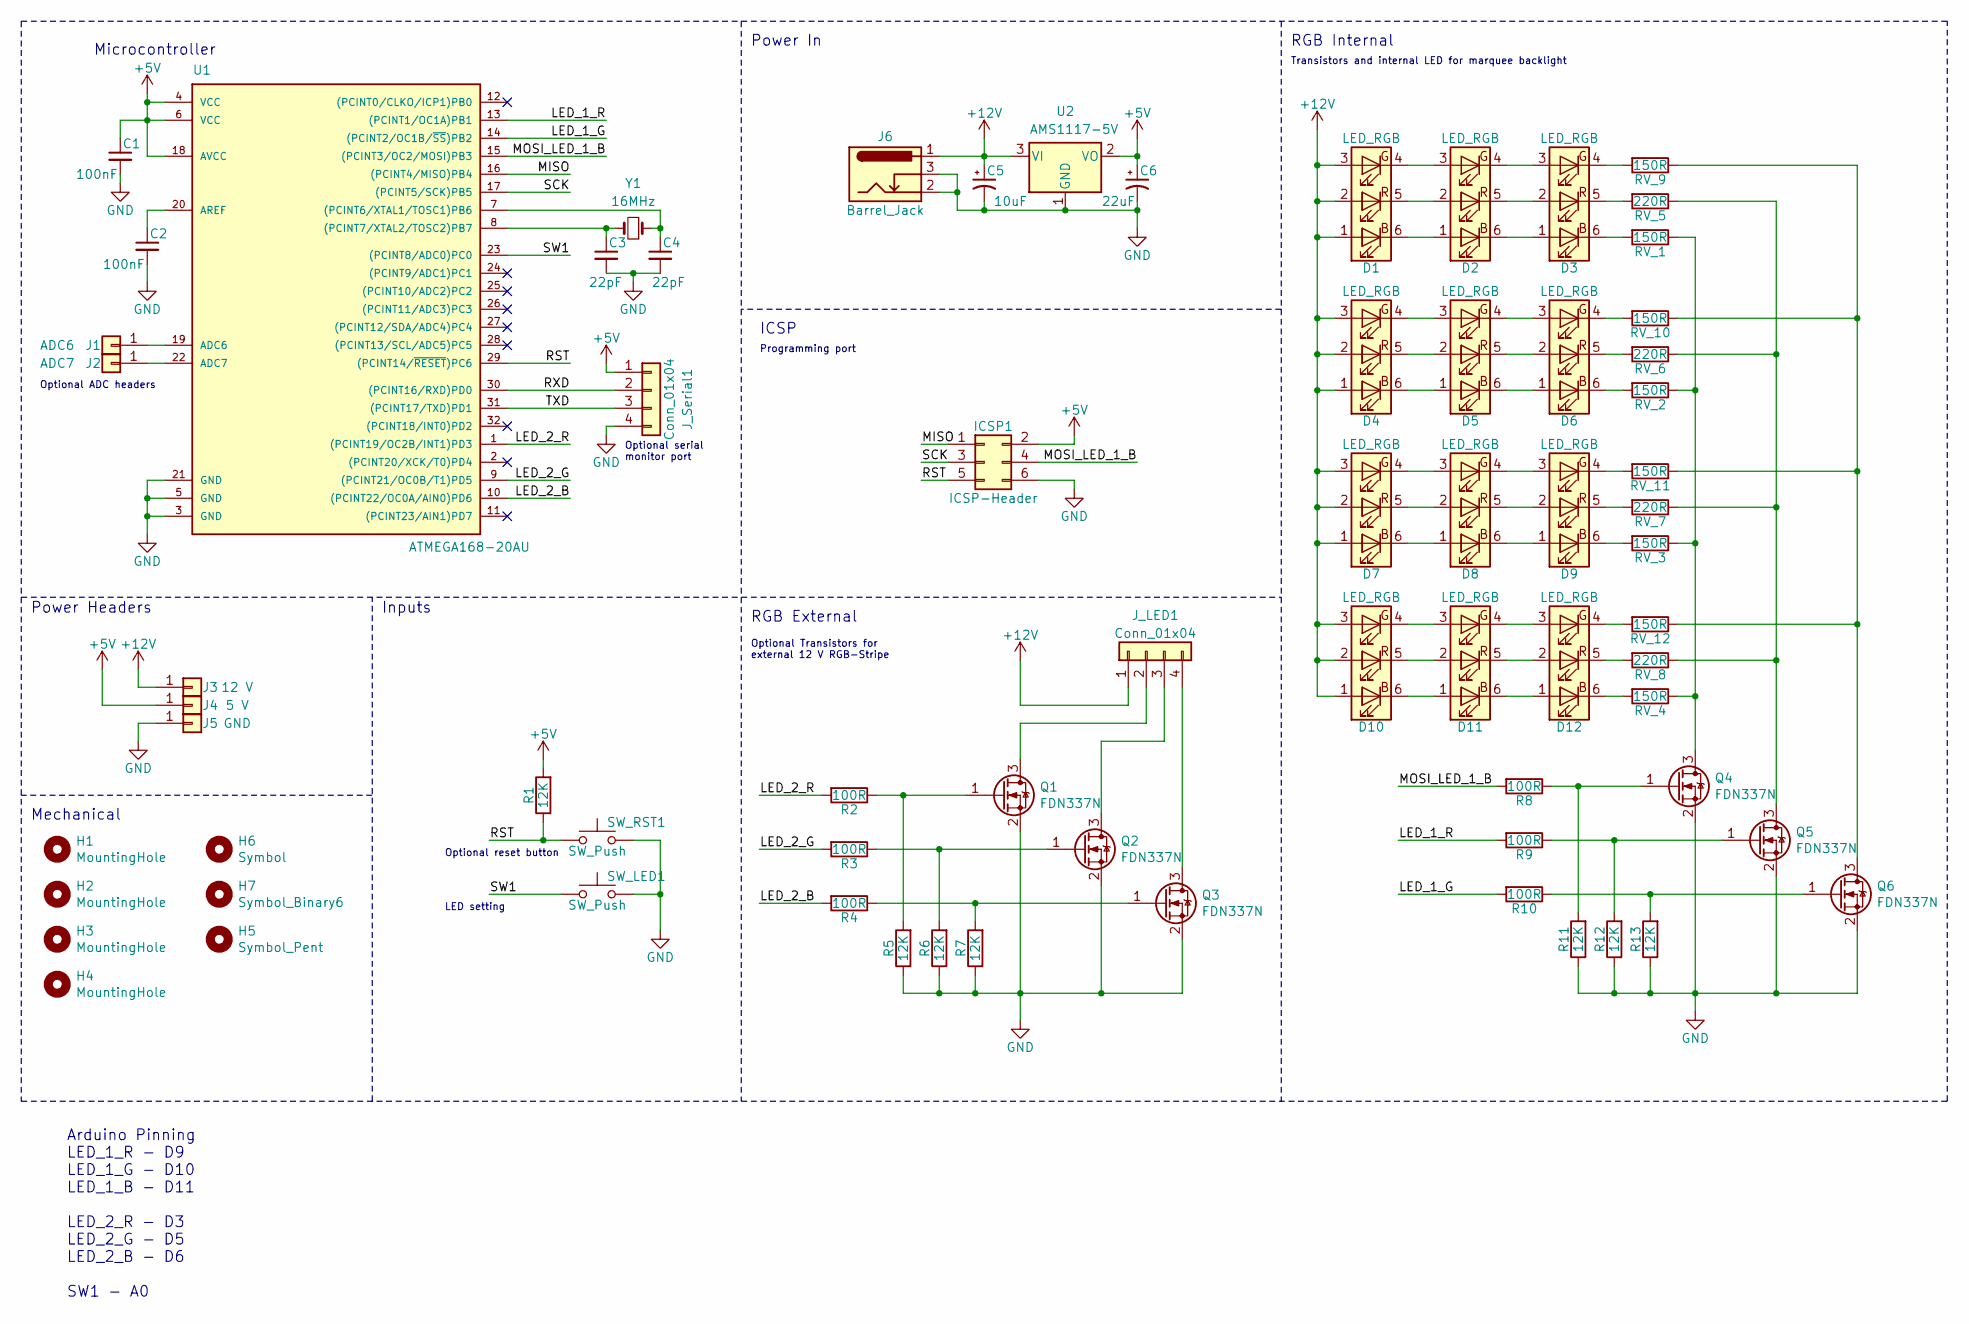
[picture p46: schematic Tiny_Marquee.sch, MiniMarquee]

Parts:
C1, C2: 100nF; C_0805_2012Metric_Pad1.15x1.40mm_HandSolder
C3, C4: 22pF; C_0805_2012Metric_Pad1.15x1.40mm_HandSolder
C5: 10uF; CP_EIA-7343-15_Kemet-W_Pad2.25x2.55mm_HandSolder
C6: 22uF; CP_EIA-3528-15_AVX-H_Pad1.50x2.35mm_HandSolder
D1, D2, D3, D4, D5, D6, D7, D8, D9, D10, D11, D12: LED_RGB; LED_RGB_5050-6
H1, H2, H3, H4: MountingHole; EigenesMountingHole_2.7mm_M2.5
H5: Symbol_Pent; PentThin
H6: Symbol; Symbol_KiCAD-Logo_CopperAndSilkScreenTop
H7: Symbol_Binary6; Binary_6_v0.1
ICSP1: ICSP-Header; AVR_ISP
J1: ADC6; PinheaderOwnWithoutSilk
J2: ADC7; PinheaderOwnWithoutSilk
J3: 12 V; PinheaderOwnWithoutSilk
J4: 5 V; PinheaderOwnWithoutSilk
J5: GND; PinheaderOwnWithoutSilk
J6: Barrel_Jack; DC_Barrel_Jack_Standing
J_LED1: Conn_01x04; PinSocket_1x04_P2.54mm_Vertical
J_Serial1: Conn_01x04; PinSocket_1x04_P2.54mm_Vertical
Q1, Q2, Q3, Q4, Q5, Q6: FDN337N; SOT-23
R1, R5, R6, R7, R11, R12, R13: 12K; R_0805_2012Metric_Pad1.15x1.40mm_HandSolder
R2, R3, R4, R8, R9, R10: 100R; R_0805_2012Metric_Pad1.15x1.40mm_HandSolder
RV_1, RV_2, RV_3, RV_4, RV_9, RV_10, RV_11, RV_12: 150R; R_0805_2012Metric_Pad1.15x1.40mm_HandSolder
RV_5, RV_6, RV_7, RV_8: 220R; R_0805_2012Metric_Pad1.15x1.40mm_HandSolder
SW_LED1: SW_Push; SW_PUSH_6mm_H9.5mm
SW_RST1: SW_Push; SW_PUSH_6mm
U1: ATMEGA168-20AU; TQFP-32_7x7mm_P0.8mm
U2: AMS1117-5V; SOT-223-3_TabPin2
Y1: 16MHz; Crystal_SMD_HC49-SD

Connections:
+5V: C1.1, C6.1, ICSP1.2, J4.1, J_Serial1.1, R1.2, U1.4 (VCC), U1.6 (VCC), U1.18 (AVCC), U2.2 (VO)
+12V: C5.1, D1.1 (RA), D1.2 (GA), D1.3 (BA), D4.1 (RA), D4.2 (GA), D4.3 (BA), D7.1 (RA), D7.2 (GA), D7.3 (BA), D10.1 (RA), D10.2 (GA), D10.3 (BA), J3.1, J6.1, J_LED1.1, U2.3 (VI)
/LED_1_G: R10.2, U1.14 ((PCINT2/OC1B/~SS~)PB2)
/LED_1_R: R9.2, U1.13 ((PCINT1/OC1A)PB1)
/LED_2_B: R4.2, U1.10 ((PCINT22/OC0A/AIN0)PD6)
/LED_2_G: R3.2, U1.9 ((PCINT21/OC0B/T1)PD5)
/LED_2_R: R2.2, U1.1 ((PCINT19/OC2B/INT1)PD3)
/MISO: ICSP1.1, U1.16 ((PCINT4/MISO)PB4)
/MOSI_LED_1_B: ICSP1.4, R8.2, U1.15 ((PCINT3/OC2/MOSI)PB3)
/RST: ICSP1.5, R1.1, SW_RST1.1, U1.29 ((PCINT14/~RESET~)PC6)
/RXD: J_Serial1.2, U1.30 ((PCINT16/RXD)PD0)
/SCK: ICSP1.3, U1.17 ((PCINT5/SCK)PB5)
/SW1: SW_LED1.1, U1.23 ((PCINT8/ADC0)PC0)
/TXD: J_Serial1.3, U1.31 ((PCINT17/TXD)PD1)
GND: C1.2, C2.2, C3.2, C4.2, C5.2, C6.2, ICSP1.6, J5.1, J6.2, J6.3, J_Serial1.4, Q1.2 (S), Q2.2 (S), Q3.2 (S), Q4.2 (S), Q5.2 (S), Q6.2 (S), R5.1, R6.1, R7.1, R11.1, R12.1, R13.1, SW_LED1.2, SW_RST1.2, U1.3 (GND), U1.5 (GND), U1.21 (GND), U2.1 (GND)
unnamed: C2.1, U1.20 (AREF)
unnamed: C3.1, U1.8 ((PCINT7/XTAL2/TOSC2)PB7), Y1.2
unnamed: C4.1, U1.7 ((PCINT6/XTAL1/TOSC1)PB6), Y1.1
unnamed: D1.4 (BK), D2.3 (BA)
unnamed: D1.5 (GK), D2.2 (GA)
unnamed: D1.6 (RK), D2.1 (RA)
unnamed: D2.4 (BK), D3.3 (BA)
unnamed: D2.5 (GK), D3.2 (GA)
unnamed: D2.6 (RK), D3.1 (RA)
unnamed: D3.4 (BK), RV_9.2
unnamed: D3.5 (GK), RV_5.2
unnamed: D3.6 (RK), RV_1.2
unnamed: D4.4 (BK), D5.3 (BA)
unnamed: D4.5 (GK), D5.2 (GA)
unnamed: D4.6 (RK), D5.1 (RA)
unnamed: D5.4 (BK), D6.3 (BA)
unnamed: D5.5 (GK), D6.2 (GA)
unnamed: D5.6 (RK), D6.1 (RA)
unnamed: D6.4 (BK), RV_10.2
unnamed: D6.5 (GK), RV_6.2
unnamed: D6.6 (RK), RV_2.2
unnamed: D7.4 (BK), D8.3 (BA)
unnamed: D7.5 (GK), D8.2 (GA)
unnamed: D7.6 (RK), D8.1 (RA)
unnamed: D8.4 (BK), D9.3 (BA)
unnamed: D8.5 (GK), D9.2 (GA)
unnamed: D8.6 (RK), D9.1 (RA)
unnamed: D9.4 (BK), RV_11.2
unnamed: D9.5 (GK), RV_7.2
unnamed: D9.6 (RK), RV_3.2
unnamed: D10.4 (BK), D11.3 (BA)
unnamed: D10.5 (GK), D11.2 (GA)
unnamed: D10.6 (RK), D11.1 (RA)
unnamed: D11.4 (BK), D12.3 (BA)
unnamed: D11.5 (GK), D12.2 (GA)
unnamed: D11.6 (RK), D12.1 (RA)
unnamed: D12.4 (BK), RV_12.2
unnamed: D12.5 (GK), RV_8.2
unnamed: D12.6 (RK), RV_4.2
unnamed: J1.1, U1.19 (ADC6)
unnamed: J2.1, U1.22 (ADC7)
unnamed: J_LED1.2, Q1.3 (D)
unnamed: J_LED1.3, Q2.3 (D)
unnamed: J_LED1.4, Q3.3 (D)
unnamed: Q1.1 (G), R2.1, R5.2
unnamed: Q2.1 (G), R3.1, R6.2
unnamed: Q3.1 (G), R4.1, R7.2
unnamed: Q4.1 (G), R8.1, R11.2
unnamed: Q4.3 (D), RV_1.1, RV_2.1, RV_3.1, RV_4.1
unnamed: Q5.1 (G), R9.1, R12.2
unnamed: Q5.3 (D), RV_5.1, RV_6.1, RV_7.1, RV_8.1
unnamed: Q6.1 (G), R10.1, R13.2
unnamed: Q6.3 (D), RV_9.1, RV_10.1, RV_11.1, RV_12.1

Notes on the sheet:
ICSP
Inputs
Microcontroller
RGB External
RGB Internal
LED setting
Optional reset button
Power In
Optional serial monitor port
Optional Transistors for external 12 V RGB-Stripe
Transistors and internal LED for marquee backlight
Programming port
Power Headers
Optional ADC headers
Mechanical
Arduino Pinning LED_1_R - D9 LED_1_G - D10 LED_1_B - D11 LED_2_R - D3 LED_2_G - D5 LED_2_B - D6 SW1 - A0

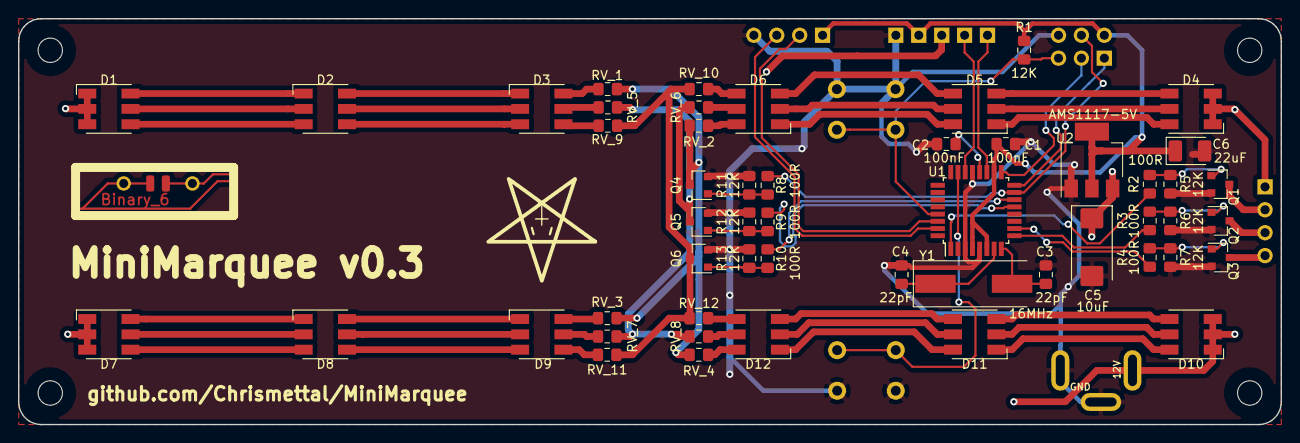
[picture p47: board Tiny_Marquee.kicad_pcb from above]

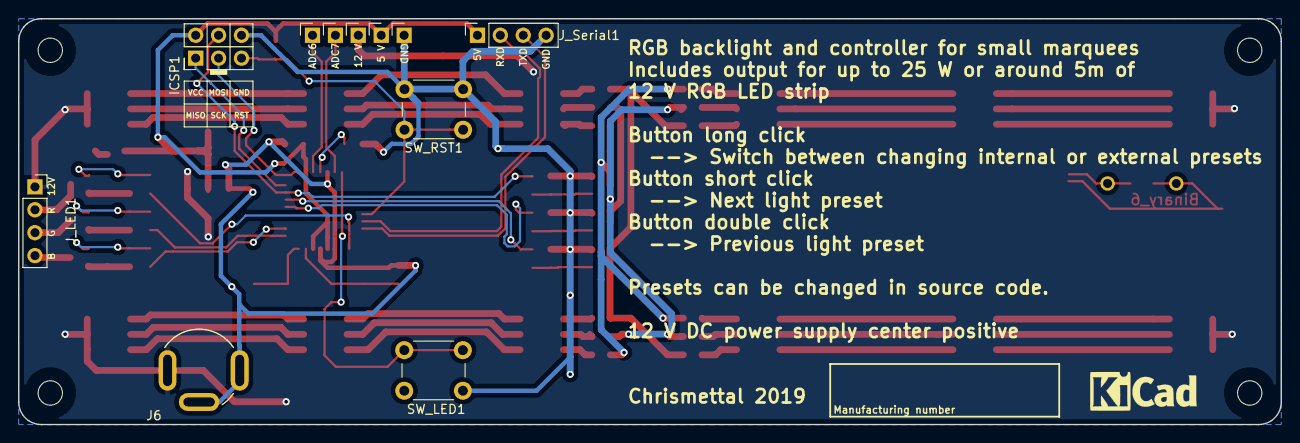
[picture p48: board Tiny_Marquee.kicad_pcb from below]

Board: 2 copper layers, 140.0 x 45.0 mm, 70 parts (12 on the bottom side), 68 nets.

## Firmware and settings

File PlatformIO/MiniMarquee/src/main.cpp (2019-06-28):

//https://github.com/Chrismettal/MiniMarquee


//Version controlling, uncomment to use the older v0.1 PCB revision
//#define PCB_v0_1

#include <Arduino.h>
#include <OneButton.h>
#include <EEPROM.h>

//Depending on PCB rev the analog outputs are either done with hardware PWM on v0.2 (analogWrite())
//or with software PWM on v0.1 (SoftPwmSet())
//This ifdef statement will replace all occurences of AnalogOut with the correct outputting function
#ifdef PCB_v0_1
  #include <SoftPWM.h>
  #define AnalogOut SoftPWMset
#else
  #define AnalogOut analogWrite
#endif

/****************************Variables*********************************/
#ifdef PCB_v0_1
//pin assignments for v0.1 with soft pwm
  const byte pin_z0_R      = 3;
  const byte pin_z0_G      = 4;
  const byte pin_z0_B      = 2;
  const byte pin_z1_R      = 5;
  const byte pin_z1_G      = 6;
  const byte pin_z1_B      = 7;
#else
//pin assignments for v0.2 without softpwm required
  const byte pin_z0_R      = 9;
  const byte pin_z0_G      = 10;
  const byte pin_z0_B      = 11;
  const byte pin_z1_R      = 5;
  const byte pin_z1_G      = 6;
  const byte pin_z1_B      = 3;
#endif
#define buttonPin A0

//RGB analog values
byte val_z0_R = 0;
byte val_z0_G = 0;
byte val_z0_B = 0;
byte val_z1_R = 0;
byte val_z1_G = 0;
byte val_z1_B = 0;

//RGB analog values to be mapped to output pin
byte out_val_z0_R = 0;
byte out_val_z0_G = 0;
byte out_val_z0_B = 0;
byte out_val_z1_R = 0;
byte out_val_z1_G = 0;
byte out_val_z1_B = 0;

//button variables
int longPressDuration         = 1000; //long press duration in ms
int doubleClickduration       = 500;  //double click duration in ms
OneButton button(buttonPin, true);    //attach OneButton to defined buttonPin

//light scene variables
bool activeLightZone  = 0;  //Switch between Zone 0 (internal) and Zone 1 (external)
byte lightScene_Zone0 = 1;  //active light scene in zone 0 
byte lightScene_Zone1 = 1;  //active light scene in zone 1
byte eeprom_addr_z0   = 0;  //eeprom space to save the light scene in zone 0
byte eeprom_addr_z1   = 1;  //eeprom space to save the light scene in zone 1

//light update timer variables
unsigned long lastUpdateTime      = 0;      //last time the output was updated
const byte updateIntervalms       = 5;     //update interval in ms
unsigned long lastFadeTime_slow   = 0;      //last time a fade light scene was updated in zone 0
unsigned long lastFadeTime_fast   = 0;      //last time a fade light scene was updated in zone 1
byte iFade_slow                   = 0;      //fading counter 0-255 zone 0
byte iFade_fast                   = 0;      //fading counter 0-255 zone 1
bool fadeDirection_slow           = 0;      //fading direction of zone 0
bool fadeDirection_fast           = 0;      //fading direction of zone 1
const byte fadeIntervalms_slow    = 50;     //fade interval slow fade | sets the speed of the slow fading scenes
const byte fadeIntervalms_fast    = 2;      //fade interval fast fade | sets the speed of the fast fading scenes

//other variables
unsigned long now = 0; //saves current milliseconds every loop cycle


/****************************Evaluate light scenes***********************/
void LightSceneEvaluation() {
  //Here you can set your own light scenes.
  //Zone0 is internal backlight
  switch (lightScene_Zone0) {
    case 1: //Red
      val_z0_R = 255;
      val_z0_G = 0;
      val_z0_B = 0;
    break;

    case 2: //Green
      val_z0_R = 0;
      val_z0_G = 255;
      val_z0_B = 0;
    break;

    case 3: //Blue
      val_z0_R = 0;
      val_z0_G = 0;
      val_z0_B = 255;
    break;

    case 4: //Sky Blue
      val_z0_R = 135;
      val_z0_G = 206;
      val_z0_B = 250;
    break;
    
    case 5: //Warm white
      val_z0_R = 255;
      val_z0_G = 239;
      val_z0_B = 210;
    break;

    case 6: //Cold white
      val_z0_R = 240;
      val_z0_G = 240;
      val_z0_B = 255;
    break;

    case 7: //Yellow
      val_z0_R = 255;
      val_z0_G = 255;
      val_z0_B = 0;
    break;

    case 8: //Orange 
      val_z0_R = 255;
      val_z0_G = 165;
      val_z0_B = 0;
    break;

    case 9: //Purple
      val_z0_R = 160;
      val_z0_G = 32;
      val_z0_B = 240;
    break;

    case 10: //Olive
      val_z0_R = 0;
      val_z0_G = 100;
      val_z0_B = 51;
    break;

    case 11: //Fade Red - Green slow
      val_z0_R = iFade_slow;
      val_z0_G = 255-iFade_slow;
      val_z0_B = 0;     
      out_val_z0_R = val_z0_R;
      out_val_z0_G = val_z0_G;
      out_val_z0_B = val_z0_B;
    break;
    
    case 12: //Fade Green - Blue slow
      val_z0_R = 0;
      val_z0_G = iFade_slow;
      val_z0_B = 255-iFade_slow;     
      out_val_z0_R = val_z0_R;
      out_val_z0_G = val_z0_G;
      out_val_z0_B = val_z0_B;
    break;

    case 13: //Fade Red - Blue slow
      val_z0_R = iFade_slow;
      val_z0_G = 0;
      val_z0_B = 255-iFade_slow;     
      out_val_z0_R = val_z0_R;
      out_val_z0_G = val_z0_G;
      out_val_z0_B = val_z0_B;
    break;

    case 14: //Fade Yellow - Blue slow
      val_z0_R = iFade_slow;
      val_z0_G = iFade_slow;
      val_z0_B = 255-iFade_slow;     
      out_val_z0_R = val_z0_R;
      out_val_z0_G = val_z0_G;
      out_val_z0_B = val_z0_B;
    break;

    case 15: //Breathing White
      val_z0_R = iFade_slow;
      val_z0_G = iFade_slow;
      val_z0_B = iFade_slow;     
      out_val_z0_R = val_z0_R;
      out_val_z0_G = val_z0_G;
      out_val_z0_B = val_z0_B;
    break;
  }

  //Zone1 is external RGB LED strip
  switch (lightScene_Zone1) {
    case 1: //Red
      val_z1_R = 255;
      val_z1_G = 0;
      val_z1_B = 0;
    break;

    case 2: //Green
      val_z1_R = 0;
      val_z1_G = 255;
      val_z1_B = 0;
    break;

    case 3: //Blue
      val_z1_R = 0;
      val_z1_G = 0;
      val_z1_B = 255;
    break;

    case 4: //Sky Blue
      val_z1_R = 135;
      val_z1_G = 206;
      val_z1_B = 250;
    break;
    
    case 5: //Warm white
      val_z1_R = 255;
      val_z1_G = 239;
      val_z1_B = 210;
    break;

    case 6: //Cold white
      val_z1_R = 240;
      val_z1_G = 240;
      val_z1_B = 255;
    break;

    case 7: //Yellow
      val_z1_R = 255;
      val_z1_G = 255;
      val_z1_B = 0;
    break;

    case 8: //Orange 
      val_z1_R = 255;
      val_z1_G = 165;
      val_z1_B = 0;
    break;

    case 9: //Purple
      val_z1_R = 160;
      val_z1_G = 32;
      val_z1_B = 240;
    break;

    case 10: //Olive
      val_z1_R = 0;
      val_z1_G = 100;
      val_z1_B = 51;
    break;

    case 11: //Fade Red - Green slow
      val_z1_R = iFade_slow;
      val_z1_G = 255-iFade_slow;
      val_z1_B = 0;     
      out_val_z1_R = val_z1_R;
      out_val_z1_G = val_z1_G;
      out_val_z1_B = val_z1_B;
    break;
    
    case 12: //Fade Green - Blue slow
      val_z1_R = 0;
      val_z1_G = iFade_slow;
      val_z1_B = 255-iFade_slow;     
      out_val_z1_R = val_z1_R;
      out_val_z1_G = val_z1_G;
      out_val_z1_B = val_z1_B;
    break;

    case 13: //Fade Red - Blue slow
      val_z1_R = iFade_slow;
      val_z1_G = 0;
      val_z1_B = 255-iFade_slow;     
      out_val_z1_R = val_z1_R;
      out_val_z1_G = val_z1_G;
      out_val_z1_B = val_z1_B;
    break;

    case 14: //Fade Yellow - Blue slow
      val_z1_R = iFade_slow;
      val_z1_G = iFade_slow;
      val_z1_B = 255-iFade_slow;     
      out_val_z1_R = val_z1_R;
      out_val_z1_G = val_z1_G;
      out_val_z1_B = val_z1_B;
    break;

    case 15: //Breathing White
      val_z1_R = iFade_slow;
      val_z1_G = iFade_slow;
      val_z1_B = iFade_slow;     
      out_val_z1_R = val_z1_R;
      out_val_z1_G = val_z1_G;
      out_val_z1_B = val_z1_B;
    break;

  }//end light scenes

}//end LightSceneEvaluation

/****************************Boot animation*****************************/
void BootAnimation() {
  //Quick boot animation
  for (byte i = 0; i < 255; i++) {
    AnalogOut(pin_z0_R, i);
    AnalogOut(pin_z1_G, i);
    delay(1);
  }
  for (byte i = 0; i < 255; i++) {
    AnalogOut(pin_z0_R, (255-i));
    AnalogOut(pin_z1_G, (255-i));
    AnalogOut(pin_z0_G, i);
    AnalogOut(pin_z1_B, i);
    delay(1);
  }
  for (byte i = 0; i < 255; i++) {
    AnalogOut(pin_z0_G, (255-i));
    AnalogOut(pin_z1_B, (255-i));
    AnalogOut(pin_z0_B, i);
    AnalogOut(pin_z1_R, i);
    delay(1);
  }
  for (byte i = 255; i > 0; i--) {
    AnalogOut(pin_z0_B, i);
    AnalogOut(pin_z1_R, i);
    delay(1);
  }
}//end bootanimation

/****************************next lightscene***************************/
void NextLightScene() {

  if (activeLightZone == 0){
    lightScene_Zone0++;
    if (lightScene_Zone0 == 16){
      lightScene_Zone0 = 1;
    }
    //permanently save light scene for rebooting
    EEPROM.write(eeprom_addr_z0, lightScene_Zone0);
  }
  if (activeLightZone == 1){
    lightScene_Zone1++;
    if (lightScene_Zone1 == 16){
      lightScene_Zone1 = 1;
    }
    //permanently save light scene for rebooting
    EEPROM.write(eeprom_addr_z1, lightScene_Zone1);
  }
}//end NextLightScene

/****************************previous lightscene*************************/
void PrevLightScene() {

  if (activeLightZone == 0){
    lightScene_Zone0--;
    if (lightScene_Zone0 == 0){
      lightScene_Zone0 = 15;
    }
    //permanently save light scene for rebooting
    EEPROM.write(eeprom_addr_z0, lightScene_Zone0);
  }
  if (activeLightZone == 1){
    lightScene_Zone1--;
    if (lightScene_Zone1 == 0){
      lightScene_Zone1 = 15;
    }
    //permanently save light scene for rebooting
    EEPROM.write(eeprom_addr_z1, lightScene_Zone1);
  }
}//end NextLightScene

/****************************Change active zone*************************/
void changeActiveZone() {
  //switch the active light zone
  if (activeLightZone == 0){

    activeLightZone = 1;

    //zone 1 animation
    for (byte i = 0; i < 255; i++) {
      AnalogOut(pin_z1_R, i);
      delayMicroseconds(500);
    }
    for (byte i = 0; i < 255; i++) {
      AnalogOut(pin_z1_G, i);
      delayMicroseconds(500);
    }
    for (byte i = 0; i < 255; i++) {
      AnalogOut(pin_z1_B, i);
      delayMicroseconds(500);
    }
    for (byte i = 255; i < 0; i--) {
      AnalogOut(pin_z1_R, i);
      delayMicroseconds(500);
    }
    for (byte i = 255; i > 0; i--) {
      AnalogOut(pin_z1_G, i);
      delayMicroseconds(500);
    }
    for (byte i = 255; i > 0; i--) {
      AnalogOut(pin_z1_B, i);
      delayMicroseconds(500);
    }

  } else {

    activeLightZone = 0;

    //zone 0 animation
    for (byte i = 0; i < 255; i++) {
      AnalogOut(pin_z0_R, i);
      delayMicroseconds(500);
    }
    for (byte i = 0; i < 255; i++) {
      AnalogOut(pin_z0_G, i);
      delayMicroseconds(500);
    }
    for (byte i = 0; i < 255; i++) {
      AnalogOut(pin_z0_B, i);
      delayMicroseconds(500);
    }
    for (byte i = 255; i < 0; i--) {
      AnalogOut(pin_z0_R, i);
      delayMicroseconds(500);
    }
    for (byte i = 255; i > 0; i--) {
      AnalogOut(pin_z0_G, i);
      delayMicroseconds(500);
    }
    for (byte i = 255; i > 0; i--) {
      AnalogOut(pin_z0_B, i);
      delayMicroseconds(500);
    }

  }
}//end NextLightScene

/*********************************Setup*********************************/
void setup() {
  //pin setup
  pinMode(pin_z0_R, OUTPUT);
  pinMode(pin_z0_G, OUTPUT);
  pinMode(pin_z0_B, OUTPUT);
  pinMode(pin_z1_R, OUTPUT);
  pinMode(pin_z1_G, OUTPUT);
  pinMode(pin_z1_B, OUTPUT);
  pinMode(buttonPin, INPUT_PULLUP);

  button.attachClick(NextLightScene);
  button.attachDoubleClick(PrevLightScene);
  button.attachLongPressStop(changeActiveZone);
  button.setClickTicks(doubleClickduration);
  button.setPressTicks(longPressDuration);

  //start software PWM for old PCB rev
  #ifdef PCB_v0_1
    SoftPWMBegin();
  #endif

  AnalogOut(pin_z0_R, 0);
  AnalogOut(pin_z0_G, 0);
  AnalogOut(pin_z0_B, 0);
  AnalogOut(pin_z1_R, 0);
  AnalogOut(pin_z1_G, 0);
  AnalogOut(pin_z1_B, 0);

  //bootup animation
  BootAnimation();

  //read EEPROM for saved light scenes
  if(EEPROM.read(eeprom_addr_z0) > 0 && EEPROM.read(eeprom_addr_z0) < 16) {
    lightScene_Zone0 = EEPROM.read(eeprom_addr_z0);
  }
  if(EEPROM.read(eeprom_addr_z1) > 0 && EEPROM.read(eeprom_addr_z1) < 16) {
    lightScene_Zone1 = EEPROM.read(eeprom_addr_z1);
  }

}//end setup

/****************************Loop*********************************/
void loop() {
  //button evaluation
  button.tick();

  now = millis();

  //imitation of for-loops that count from 0 to 255 and back in defined intervals
  //for changing light scenes
  if ( (lastFadeTime_slow + fadeIntervalms_slow) < now ) {
    lastFadeTime_slow = now;
    if(fadeDirection_slow == 0) iFade_slow++; else iFade_slow--;
    if((iFade_slow == 255) | (iFade_slow == 0)) fadeDirection_slow = !fadeDirection_slow;             
  }
  if ( (lastFadeTime_fast + fadeIntervalms_fast) < now ) {
    lastFadeTime_fast = now;
    if(fadeDirection_fast == 0) iFade_fast++; else iFade_fast--;
    if((iFade_fast == 255) | (iFade_fast == 0)) fadeDirection_fast = !fadeDirection_fast;             
  }

  //lightscene evaluation
  LightSceneEvaluation();
  
  //update outputs in specified interval
  if ( (lastUpdateTime + updateIntervalms) < now ) {
    
    //save current time for next interval
    lastUpdateTime = now;

    //fade to new value before outputting
    if (out_val_z0_R < val_z0_R) out_val_z0_R++;
    if (out_val_z0_G < val_z0_G) out_val_z0_G++;
    if (out_val_z0_B < val_z0_B) out_val_z0_B++;
    if (out_val_z1_R < val_z1_R) out_val_z1_R++;
    if (out_val_z1_G < val_z1_G) out_val_z1_G++;
    if (out_val_z1_B < val_z1_B) out_val_z1_B++;
    if (out_val_z0_R > val_z0_R) out_val_z0_R--;
    if (out_val_z0_G > val_z0_G) out_val_z0_G--;
    if (out_val_z0_B > val_z0_B) out_val_z0_B--;
    if (out_val_z1_R > val_z1_R) out_val_z1_R--;
    if (out_val_z1_G > val_z1_G) out_val_z1_G--;
    if (out_val_z1_B > val_z1_B) out_val_z1_B--;

    //Output values to analog pins
    AnalogOut(pin_z0_R, out_val_z0_R);
    AnalogOut(pin_z0_G, out_val_z0_G);
    AnalogOut(pin_z0_B, out_val_z0_B);
    AnalogOut(pin_z1_R, out_val_z1_R);
    AnalogOut(pin_z1_G, out_val_z1_G);
    AnalogOut(pin_z1_B, out_val_z1_B);

  }//end update interval

}//end Loop

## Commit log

2019-05-31 Updated source for use with PCB v0.1 and v0.2
2019-05-31 Uploaded pcb pictures
2019-05-31 Inserted and renamed pictures
2019-05-31 Fixed sourcecode for both hw versions
    [main.cpp]
2019-06-08 Fixed loading lightscenes on reboot
    [main.cpp]
2019-06-09 Upload more material
    [Case_singlecolor.stl, Case_singlecolor_r2.stl, NES_blk.stl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]
2019-06-09 Added more shields
    [GC_bl.stl, GC_blu.stl, GC_wh.stl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]
2019-06-09 Added even mode shields
    [PS2_blk.stl, PS2_clr.stl, PS2_wh.stl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]
2019-06-10 Made more signs
    [Xbox360_blk.stl, Xbox360_grn.stl, Xbox360_wh.stl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]
2019-06-10 Switched folder layout
    [GC_bl.stl, GC_blu.stl, GC_wh.stl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]
2019-06-10 Added raw sign files
    [RawSign_blk.stl, RawSign_wh.stl]
2019-06-20 Added more frontpanels
    [2600_blk.stl, 2600_clr.stl, 2600_red.stl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]
2019-06-21 New revision of case with diffusor and new light scenes
    [Case_singlecolor_r2.stl, Case_singlecolor_r3.stl, Diffusor_wh.stl]
2019-06-21 Fixed light scene bug
    [Case_singlecolor_r3.stl, Case_singlecolor_r4.stl]
2021-01-16 Update to v0.3, switching C5 to 10uF, 35 V.
    [MiniMarquee_v0.2_BOM.ods, MiniMarquee_v0.3_BOM.ods, Tiny_Marquee.kicad_pcb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]
2021-01-16 Cut away version number from logo
